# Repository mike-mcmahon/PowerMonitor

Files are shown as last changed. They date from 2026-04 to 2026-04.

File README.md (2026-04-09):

# PowerMonitor

## Table of Contents
- [Introduction](#introduction)
- [Documentation](#documentation)
- [Source Code](#source-code)

- [Information - Particle.io](#information---particleio)
- [Prerequisites To Use This Repository (Software)](#prerequisites-to-use-this-repository-software)
- [Getting Started](#getting-started)

- [License](#license)
- [Support and Feedback](#support-and-feedback)

## Introduction

This project was started to create a device that monitors AC voltage and to send push notifications to a users smartphone upon loss and restoration of power.

This device comes in handy if you ever are concerned about the loss of power in your home or at your cottage.  The user will receive push notifications via cellular (LTE CAT M1) when power is lost
and retored.  Battery backup lasts at least one day *(usually more)*.  No reliance on wifi or ethernet based network connectivity; though you should ensure you have cellular reception in the 
area you plan to deploy this.  *No subscription or data plan is required when using this device.*

For details of what this product can *currently* do for you, please read the user manual included in the documentation section of this repository.
The project was intended to be a product/device for sale; however, I have decided to open source it.  Users have the option to use these project files to make their own device, or you can optionally contact me to manufacture and program part, or all, of this project for a *fee*.  

## Documentation:

Included in this repository are the Fusion360 files for 3D models and the electronics required to make this device along with printouts of the schematics.
To use this device you will be required to:
-	Have a Particle.io account and device
-	Pushover.net account

The included user manual provides information that details the features and functionality of the device.  Additional setup guides provide instruction on proper battery installation, and on how to setup your Pushover account.
To set up your account on Particle.io see the documentation below and online at [Particle.io](https://www.particle.io/).  In the future I may provide a setup guide for creating/implementing the required custom webhook for Pushover.
*Note again that this was a device I had intended to sell, so keep this in mind while reading the documentation.*

## Source Code:

You will need VS Code installed on your system along with the Particle Workbench extension.
  
Please note that I have built this application on DeviceOS 6.0.0.

See [Getting Started](#getting-started) for further information.

## Information - Particle.io

The firmware in this project was created using [Particle Developer Tools](https://www.particle.io/developer-tools/).

## Prerequisites To Use This Repository (Software)

To use this software/firmware you'll need:

- A BRN404X [Particle Device](https://www.particle.io/devices/).
- Windows/Mac/Linux for building the software and flashing it to a device.
- [Particle Development Tools](https://docs.particle.io/getting-started/developer-tools/developer-tools/) installed and set up on your computer.  VC Code with Particle Workbench installed is recommended.
- [Pushover.net](https://pushover.net/) account set up and User key along with API token created.  See setup guide included in the documentation section of this repository.

## Getting Started

1. While not essential, it is recommended to run the [device setup process](https://setup.particle.io/) on your Particle device first. This ensures your device's firmware is up-to-date and you have a solid baseline to start from.

2. If you haven't already, open this project in Visual Studio Code (File -> Open Folder). 

3. There are two spots in the source code that you are required to update with your own information.
  - .vscode/settings.json
    - Update `"particle.targetDevice”: “xxxxxxx”` with `xxxxxxxx` being the correct device name for your Particle Device as configured on Particle.io.
  - datatransmit.cpp
    - Update `Particle.publish("yyyyyyyy", pushoverPacket, PRIVATE);` in the file datatransmit.cpp where `yyyyyyyy` is the event name you created for the custom webhook.

4. Then [compile and flash](https://docs.particle.io/getting-started/developer-tools/workbench/#cloud-build-and-flash) your device. Ensure your device's USB port is connected to your computer.

5. Refer to the user manual included in this repository on the functionality the PowerMonitor provides and verify the device is working.

## License:

Copyright (C) 2025 Mike McMahon.  Creative Commons CC BY-NC-SA 4.0 License applies to all files in this repository.  See LICENSE.md for details.

## Support and Feedback

Contact me at [mike@3rdgear.ca] or [mike@cypressembeddedsystems.ca]

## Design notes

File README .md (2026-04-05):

# PowerMonitor

Introduction:
This project was started to create a device that monitors AC voltage and to send push notifications to a users smartphone upon loss of power.
For details of what this product can (currently) do for you, please read the user manual included in the documentation section of this repository.
The project was intended to be a device for sale; however, I have decided to open source it.  Users have the option to use these project files to make their own device, or you can optionally contact me to manufacture and program parts, or all of this project for a fee.  

Documentation:
Included in this repository are the Fusion360 files for 3D models and the electronics required to make this device along with printouts of the schematics and mechanical general assembly drawings.
To use this device you will be required to:
-	Have a Particle.io account and device
-	Pushover.net account
The included user manual provides information that details the features and functionality of the device.  Additional setup guides provide instruction on proper battery installation, and on how to setup your Pushover account.
To set up your account on Particle.io see the documentation below.  In the future I may provide a setup guide for creating/implementing the required custom webhook for Pushover.
Note again that this was a device I had intended to sell, so keep this in mind while reading the documentation.

Source Code:
You will need VS Code installed on your system.
Please note that there are two spots in the source code that you are required to update with your own information.
1.	.vscode/settings.json
Update “particle.targetDevice”: “xxxxxxx” with the correct device name for your Particle Device as configured on Particle.io.
2.	Update Particle.publish("yyyyyyyy", pushoverPacket, PRIVATE); in the file datatransmit.cpp where “yyyyyyyy” is the event name you created for the custom webhook.
Please note that I have built this application on DeviceOS 6.0.0.

License:
Copyright (C) 2025 Mike McMahon.  Creative Commons CC BY-NC-SA 4.0 License applies to all files in this repository.  See LICENSE.md for details.

~~~~~~~~~~~~~~~~~~~~~~~~~~~~~~~~~~~~~~~~~~~~~~~~~~~~~~~~~~~~~~~~~~~~~~~~~~~~~~~~~~~~~~~~~~~~~~~~~~~~~~~~~~~~~~~~~~~~~~~~~~~~~~~~~~~~~~~~~~~~~~~~~
~~~~~~~~~~~~~~~~~~~~~~~~~~~~~~~~~~~~~~~~~~~~~~~~~~~~~~~~~~~~~~~~~~~~~~~~~~~~~~~~~~~~~~~~~~~~~~~~~~~~~~~~~~~~~~~~~~~~~~~~~~~~~~~~~~~~~~~~~~~~~~~~~
Autogenerated file information from Particle Workbench

# PowerMonitor

This firmware project was created using [Particle Developer Tools](https://www.particle.io/developer-tools/) and is compatible with all [Particle Devices](https://www.particle.io/devices/).

Feel free to replace this README.md file with your own content, or keep it for reference.

## Table of Contents
- [Introduction](#introduction)
- [Prerequisites To Use This Template](#prerequisites-to-use-this-repository)
- [Getting Started](#getting-started)
- [Particle Firmware At A Glance](#particle-firmware-at-a-glance)
  - [Logging](#logging)
  - [Setup and Loop](#setup-and-loop)
  - [Delays and Timing](#delays-and-timing)
  - [Testing and Debugging](#testing-and-debugging)
  - [GitHub Actions (CI/CD)](#github-actions-cicd)
  - [OTA](#ota)
- [Support and Feedback](#support-and-feedback)
- [Version](#version)

## Introduction

For an in-depth understanding of this project template, please refer to our [documentation](https://docs.particle.io/firmware/best-practices/firmware-template/).

## Prerequisites To Use This Repository

To use this software/firmware on a device, you'll need:

- A [Particle Device](https://www.particle.io/devices/).
- Windows/Mac/Linux for building the software and flashing it to a device.
- [Particle Development Tools](https://docs.particle.io/getting-started/developer-tools/developer-tools/) installed and set up on your computer.
- Optionally, a nice cup of tea (and perhaps a biscuit).

## Getting Started

1. While not essential, we recommend running the [device setup process](https://setup.particle.io/) on your Particle device first. This ensures your device's firmware is up-to-date and you have a solid baseline to start from.

2. If you haven't already, open this project in Visual Studio Code (File -> Open Folder). Then [compile and flash](https://docs.particle.io/getting-started/developer-tools/workbench/#cloud-build-and-flash) your device. Ensure your device's USB port is connected to your computer.

3. Verify the device's operation by monitoring its logging output:
    - In Visual Studio Code with the Particle Plugin, open the [command palette](https://docs.particle.io/getting-started/developer-tools/workbench/#particle-commands) and choose "Particle: Serial Monitor".
    - Or, using the Particle CLI, execute:
    ```
    particle serial monitor --follow
    ```

4. Uncomment the code at the bottom of the cpp file in your src directory to publish to the Particle Cloud! Login to console.particle.io to view your devices events in real time.

5. Customize this project! For firmware details, see [Particle firmware](https://docs.particle.io/reference/device-os/api/introduction/getting-started/). For information on the project's directory structure, visit [this link](https://docs.particle.io/firmware/best-practices/firmware-template/#project-overview).

## Particle Firmware At A Glance

### Logging

The firmware includes a [logging library](https://docs.particle.io/reference/device-os/api/logging/logger-class/). You can display messages at different levels and filter them:

```
Log.trace("This is trace message");
Log.info("This is info message");
Log.warn("This is warn message");
Log.error("This is error message");
```

### Setup and Loop

Particle projects originate from the Wiring/Processing framework, which is based on C++. Typically, one-time setup functions are placed in `setup()`, and the main application runs from the `loop()` function.

For advanced scenarios, explore our [threading support](https://docs.particle.io/firmware/software-design/threading-explainer/).

### Delays and Timing

By default, the setup() and loop() functions are blocking whilst they run, meaning that if you put in a delay, your entire application will wait for that delay to finish before anything else can run. 

For techniques that allow you to run multiple tasks in parallel without creating threads, checkout the code example [here](https://docs.particle.io/firmware/best-practices/firmware-template/).

(Note: Although using `delay()` isn't recommended for best practices, it's acceptable for testing.)

### Testing and Debugging

For firmware testing and debugging guidance, check [this documentation](https://docs.particle.io/troubleshooting/guides/build-tools-troubleshooting/debugging-firmware-builds/).

### GitHub Actions (CI/CD)

This project provides a YAML file for GitHub, automating firmware compilation whenever changes are pushed. More details on [Particle GitHub Actions](https://docs.particle.io/firmware/best-practices/github-actions/) are available.

### OTA

To learn how to utilize Particle's OTA service for device updates, consult [this documentation](https://docs.particle.io/getting-started/cloud/ota-updates/).

Test OTA with the 'Particle: Cloud Flash' command in Visual Studio Code or the CLI command 'particle flash'!

This firmware supports binary assets in OTA packages, allowing the inclusion of audio, images, configurations, and external microcontroller firmware. More details are [here](https://docs.particle.io/reference/device-os/api/asset-ota/asset-ota/).

## Support and Feedback

For support or feedback on this template or any Particle products, please join our [community](https://community.particle.io)!

## Version

Template version 1.0.2

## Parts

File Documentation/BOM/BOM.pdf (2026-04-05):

Miscellaneous BOM Items

Component | Part Number | Description | Qty | UoM | Vendor
Inserts | n/a | 5mm brass threaded inserts | 4 | each | Amazon
Screws | 99461A942 | 18-8 SS thread forming screw, M3x10mm | 9 | each | McMaster-Car
Screws | 91294A128 | M3x8mm flat head screw | 4 | each | McMaster-Car
Power Supply | DC23U | SoulBay DC23U micro USB 5Vdc ps | 1 | each | Amazon
Battery | MAK010-P | Mbot Slim Lipo Battery, 3.7V 1800mAh | 1 | each | RobotShop

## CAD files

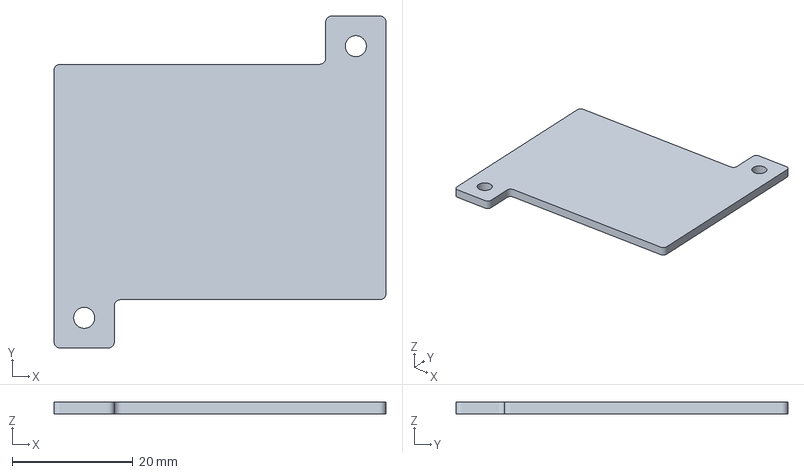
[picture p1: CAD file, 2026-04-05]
Documentation/Fusion360 CAD Models/PrusaSlicer Project Files/Battery Cover/Battery Cover v7 - Spectrum ASA-X GF10.3mf
55.0 x 55.0 x 2.00 mm

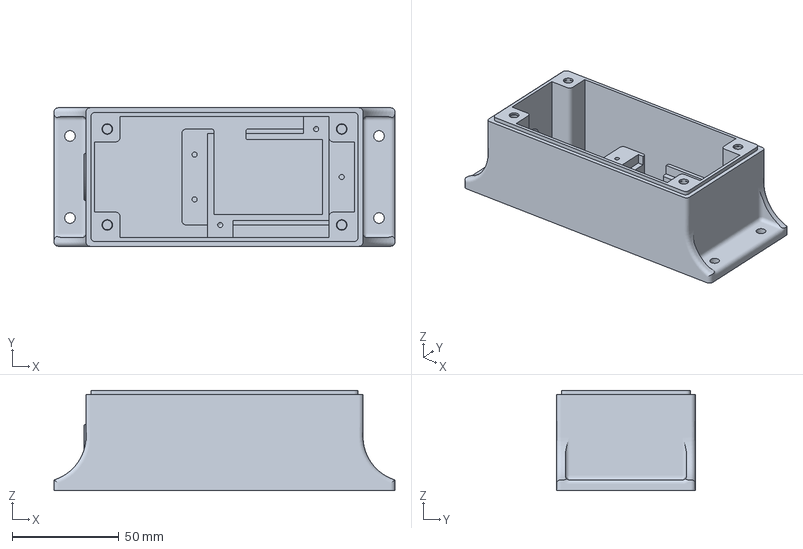
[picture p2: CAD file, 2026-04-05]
Documentation/Fusion360 CAD Models/PrusaSlicer Project Files/Enclosure Bottom/Power Monitor Enclosure Bottom v34 - Spectrum ASA-X GF10.3mf
160.0 x 65.0 x 47.0 mm

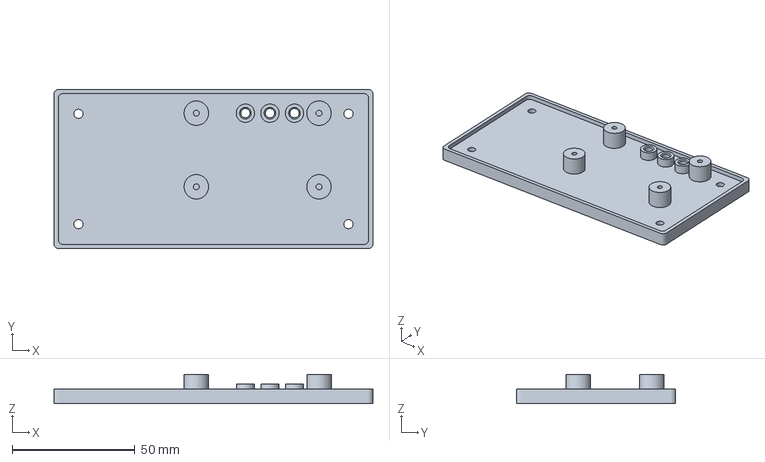
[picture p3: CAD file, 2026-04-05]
Documentation/Fusion360 CAD Models/PrusaSlicer Project Files/Enclosure Lid/Enclosure Lid v23 - Spectrum ASA-X GF10.3mf
130.0 x 65.0 x 12.0 mm

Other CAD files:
Documentation/Fusion360 CAD Models/Fusion360/Battery Cover/Battery Cover.f3d
Documentation/Fusion360 CAD Models/Fusion360/Enclosure Bottom/Power Monitor Enclosure Bottom.f3d
Documentation/Fusion360 CAD Models/Fusion360/Enclosure Lid/Enclosure Lid.f3d
Documentation/Fusion360 Electrical/Carrier Board/BRN404X Carrier Board.f3z
Documentation/Fusion360 Electrical/LED Board/Power Monitor Electronics Design.f3z

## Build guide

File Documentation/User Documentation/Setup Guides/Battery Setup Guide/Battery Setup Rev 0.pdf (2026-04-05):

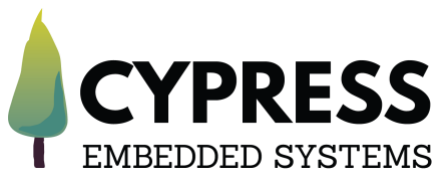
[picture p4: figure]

Cypress Embedded Systems | Setup Guide rev. 0

©2025 Michael McMahon, Cypress Embedded Systems. All rights reserved. This work is licensed under a Creative Commons Attribution-NonCommercial-ShareAlike 4.0 International License. You should have received a copy of the license along with this work. If not, see http://creativecommons.org/licenses/by-nc-sa/4.0/.

# PowerMonitor AC Line Voltage Monitoring Device Setup Guide

IMPORTANT! The following instructions are to be followed before using the PowerMonitor for the first time.

INFORMATION

1) Read the user manual for the PowerMonitor and become familiar with its external and internal features.
2) Plug in the battery before first use.
a. Unscrew the four (4) M3 flat head screws using the supplied Allen key, and remove the cover.
b. READ THE SECTION ON INTERNAL FEATURES IN THE USER MANUAL. The JST battery connectors are polarized. There is no reverse polarity protection on this unit. Damage from connecting the battery incorrectly is not covered by any warranty.
c. Connect the battery to the main control board as shown in the User Manual.
d. Put the cover back onto the PowerMonitor and secure it with the same four (4) screws that were removed in step a.
3) You may now use the PowerMonitor with the supplied microUSB power supply.

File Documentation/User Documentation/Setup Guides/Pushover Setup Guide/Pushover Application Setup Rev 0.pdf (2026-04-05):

## PowerMonitor AC Line Voltage Monitoring Device – Pushover Application Setup

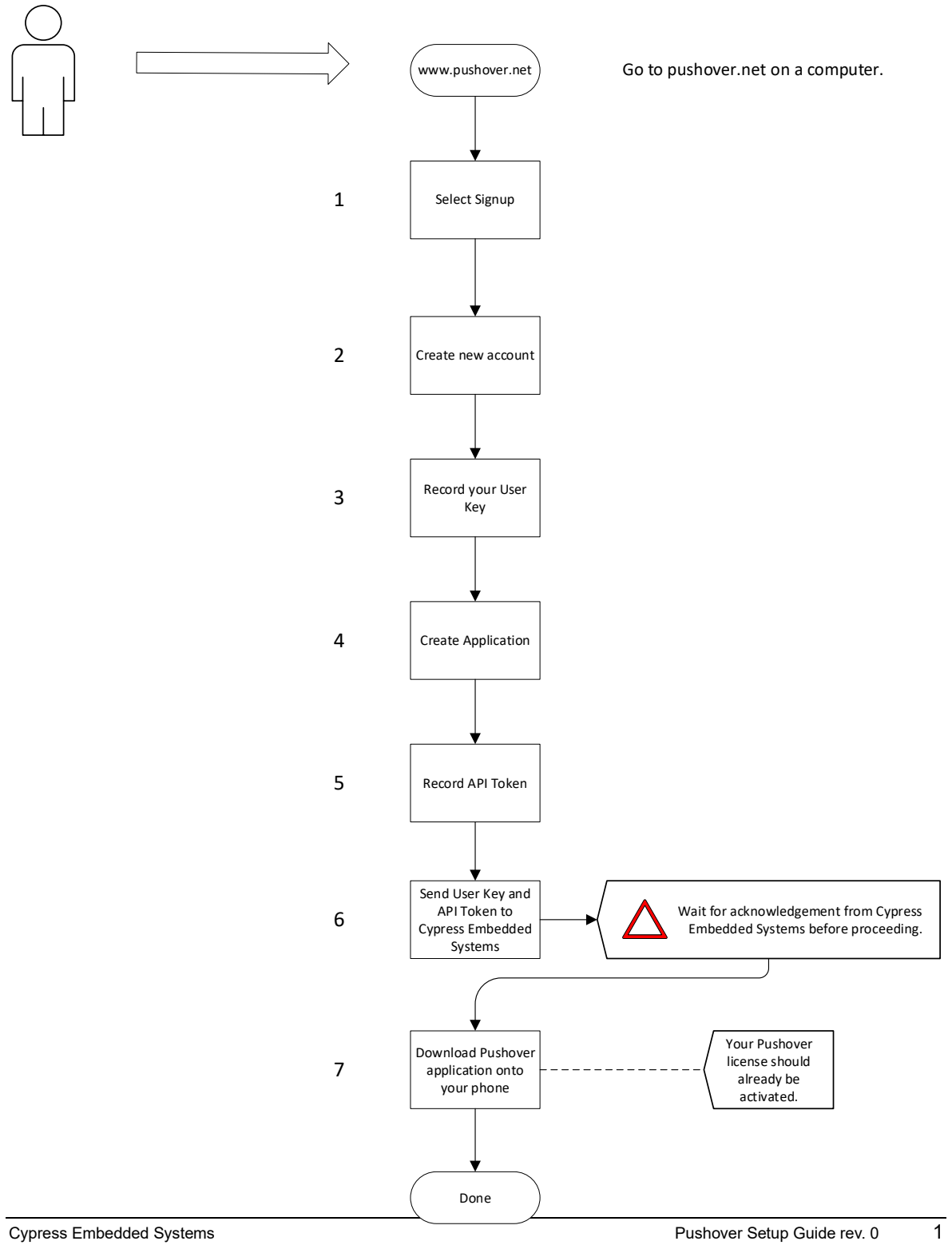
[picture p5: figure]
Cypress Embedded Systems; Pushover Setup Guide rev. 0; Select Signup; Create new account; Record your User Key; Create Application; Record API Token; Send User Key and API Token to Cypress Embedded Systems; Download Pushover application onto your phone; Done; Your Pushover license should already be activated.; Wait for acknowledgement from Cypress Embedded Systems before proceeding.

©2025 Michael McMahon, Cypress Embedded Systems. All rights reserved. This work is licensed under a Creative Commons Attribution-NonCommercial-ShareAlike 4.0 International License. You should have received a copy of the license along with this work. If not, see http://creativecommons.org/licenses/by-ncsa/4.0/.

www.pushover.net | Go to pushover.net on a computer.

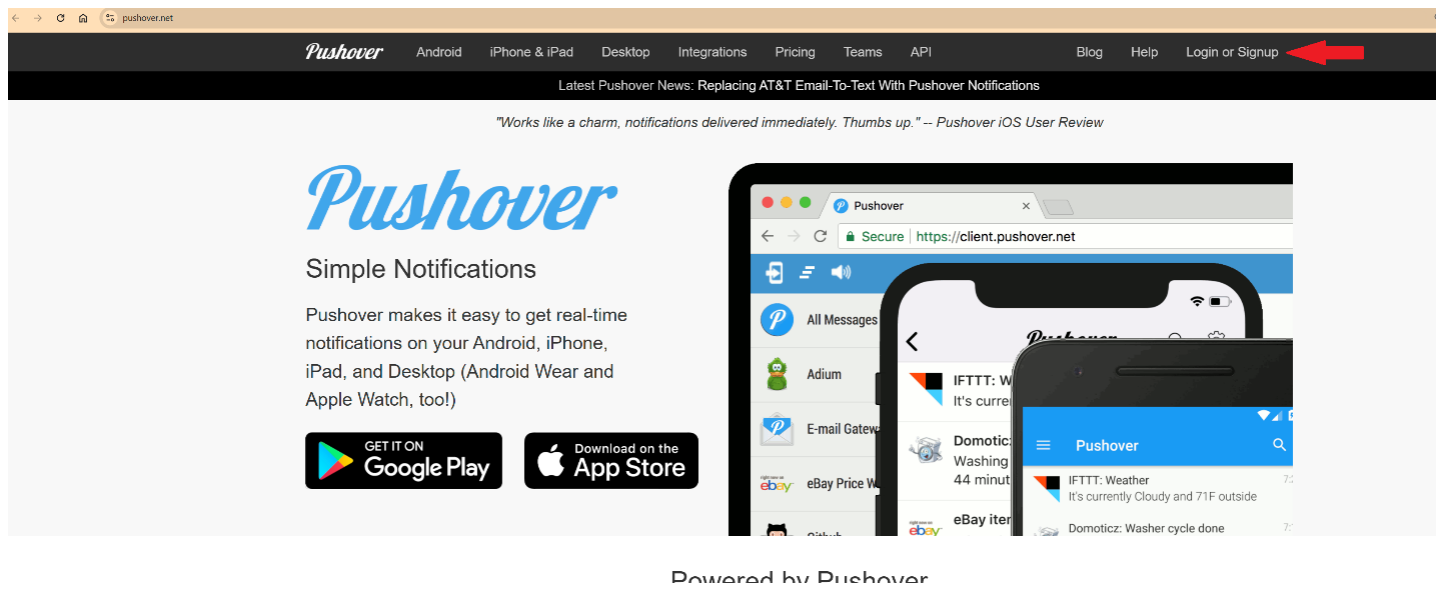
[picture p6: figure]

Cypress Embedded Systems | Pushover Setup Guide rev. 0 | 2

©2025 Michael McMahon, Cypress Embedded Systems. All rights reserved. This work is licensed under a Creative Commons Attribution-NonCommercial-

### 1. Select Signup

a. From a computer, open the website pushover.net.
b. In the top right corner of Figure 1 - Pushover landing page, click on “Login or Signup”.

## Figure 1 - Pushover landing page

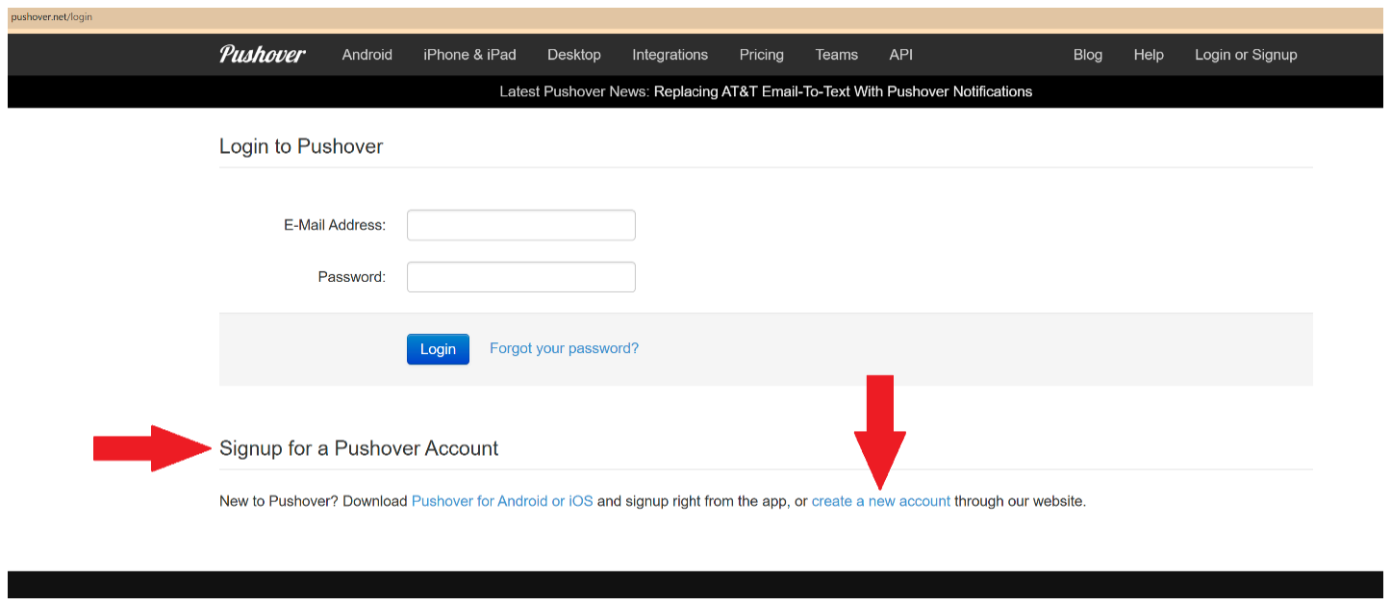
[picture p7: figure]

Cypress Embedded Systems | Pushover Setup Guide rev. 0 | 3

©2025 Michael McMahon, Cypress Embedded Systems. All rights reserved. This work is licensed under a Creative Commons Attribution-NonCommercial-

### 2. Create new account a. From the new web page that opened, Figure 2 - Create a new account, select the link to

"create a new account".

## Figure 2 - Create a new account

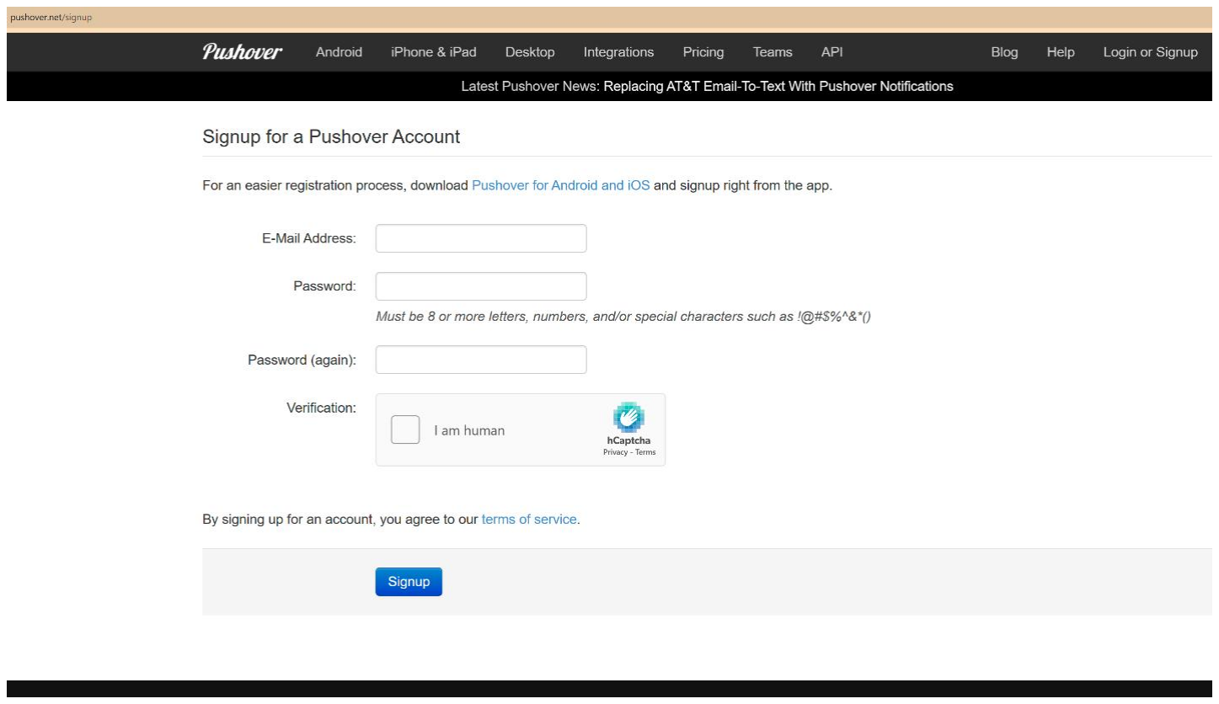
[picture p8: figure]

Cypress Embedded Systems | Pushover Setup Guide rev. 0 | 4

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

### b. On the page that opens, Figure 3 – Signup for a Pushover Account, enter your email address and password. Make sure to record and remember the email address and

password you used.

INFORMATION

Yor are responsible for saving and maintaining this information.

# This information will be needed later when you set up the

Pushover application on your smartphone.

c. Click on the box "I am human".
d. Click on the button "Signup".

## Figure 3 – Signup for a Pushover Account

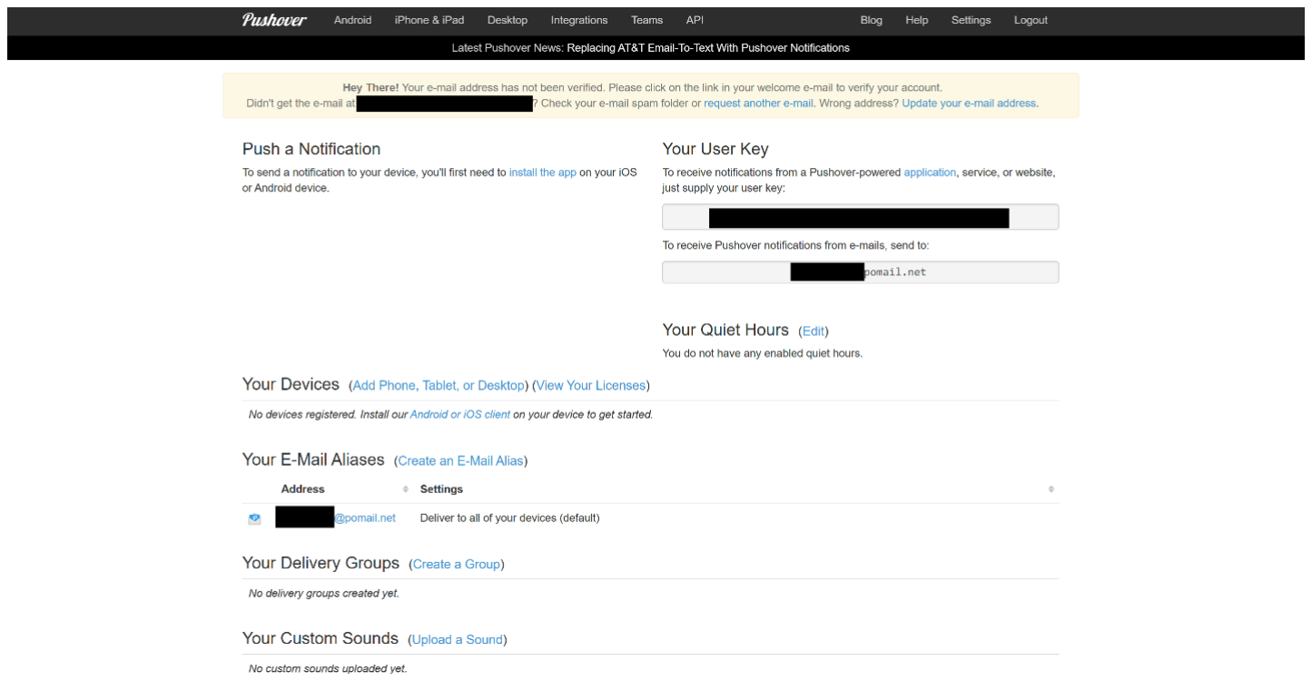
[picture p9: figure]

Cypress Embedded Systems | Pushover Setup Guide rev. 0 | 5

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

### e. Once your account is created, you will be redirected to the Pushover home page, Figure

4 - Account home page, for your account.

INFORMATION

# You will also receive an email from Pushover to verify your

account. Follow the directions in this email.

## Figure 4 - Account home page

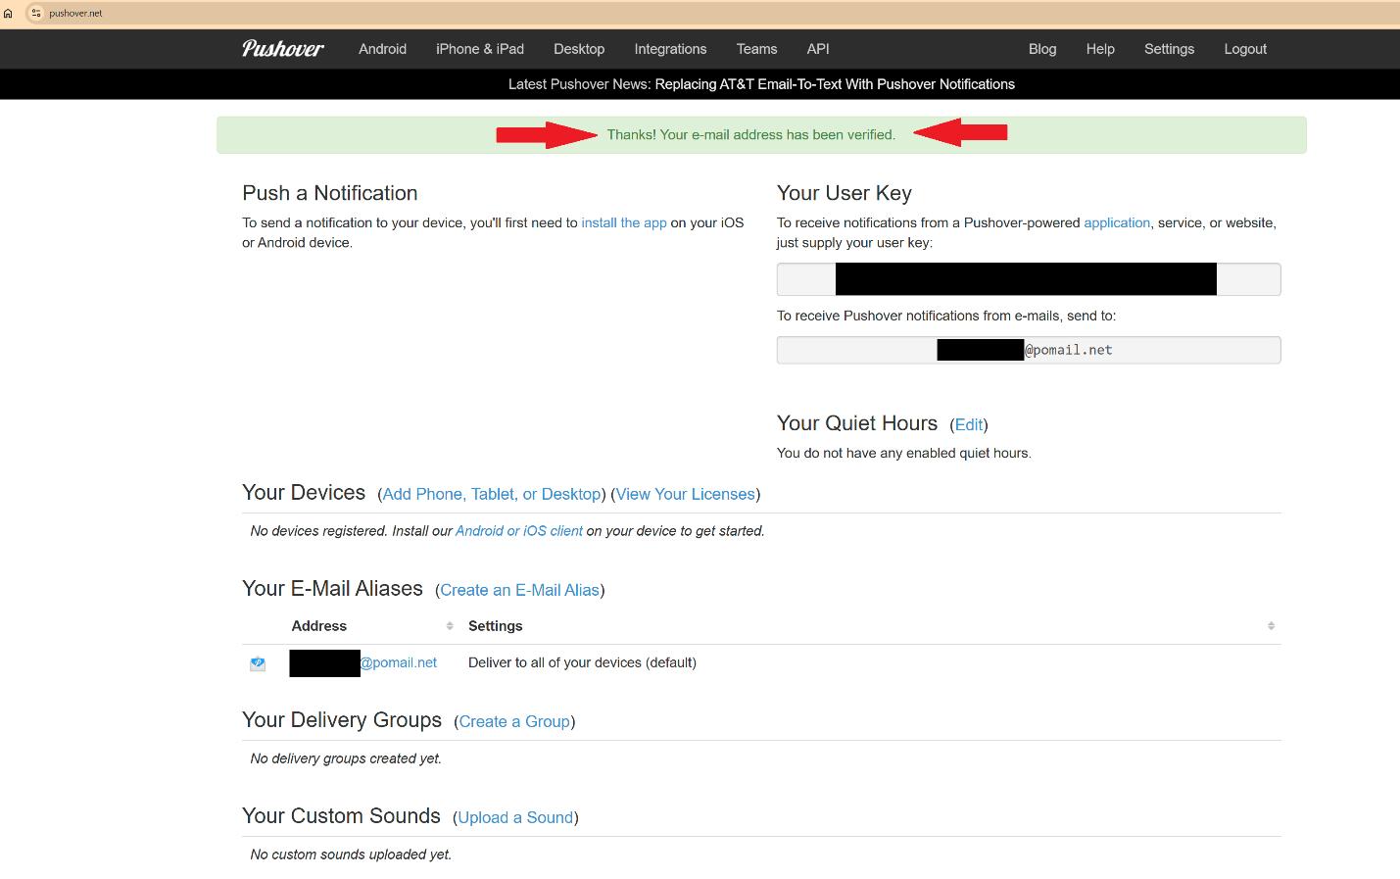
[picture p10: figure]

Cypress Embedded Systems | Pushover Setup Guide rev. 0 | 6

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

### f. Once your account is verified, there will be a green banner shown at the top of your

account home page as shown in Figure 5 - Verified account home page.

## Figure 5 - Verified account home page

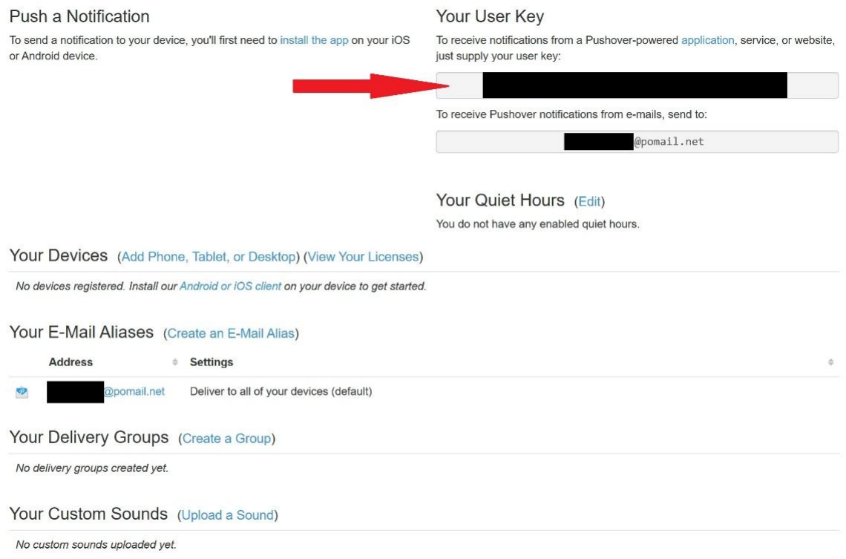
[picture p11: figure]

Cypress Embedded Systems | Pushover Setup Guide rev. 0 | 7

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

### 3. Record your User Key a. At the top right side of the account home page is "Your User Key', see Figure 6 - User Key. This is an alphanumeric string. Please take a screenshot of this and save it to your

computer.

INFORMATION

# You will need to send your user key to Cypress Embedded Systems. This is one of two pieces of information that are needed

to get your PowerMonitor to work.

## Figure 6 - User Key

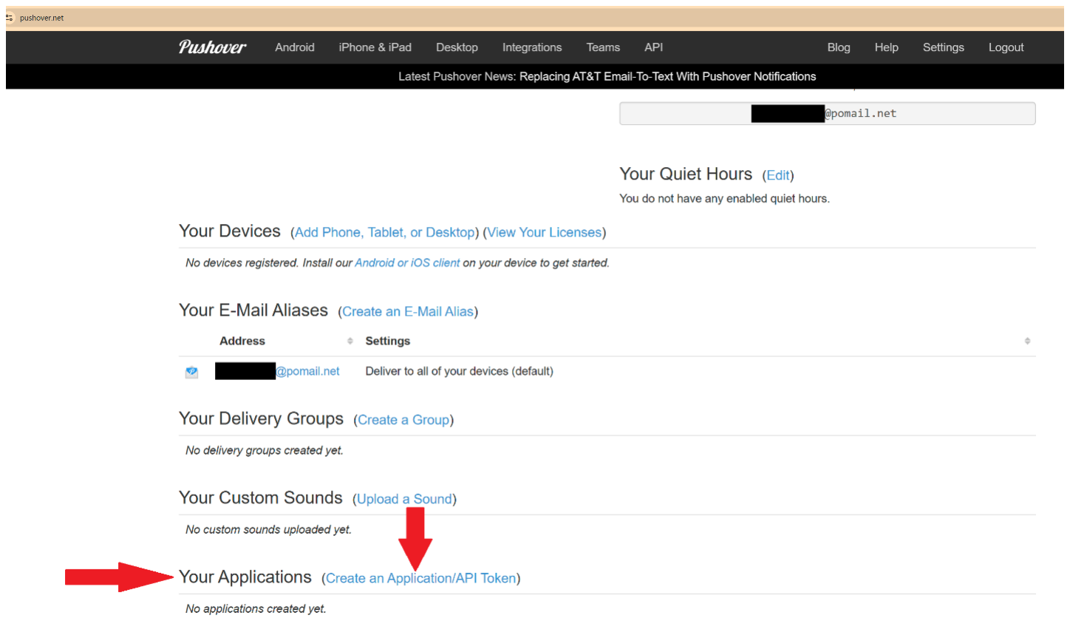
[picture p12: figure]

Cypress Embedded Systems | Pushover Setup Guide rev. 0 | 8

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

### 4. Create Application a. At the bottom of your account home page is a section called "Your Applications", see

Figure 7 - Your Applications. Click on the link called "Create an Application/API Token".

## Figure 7 - Your Applications

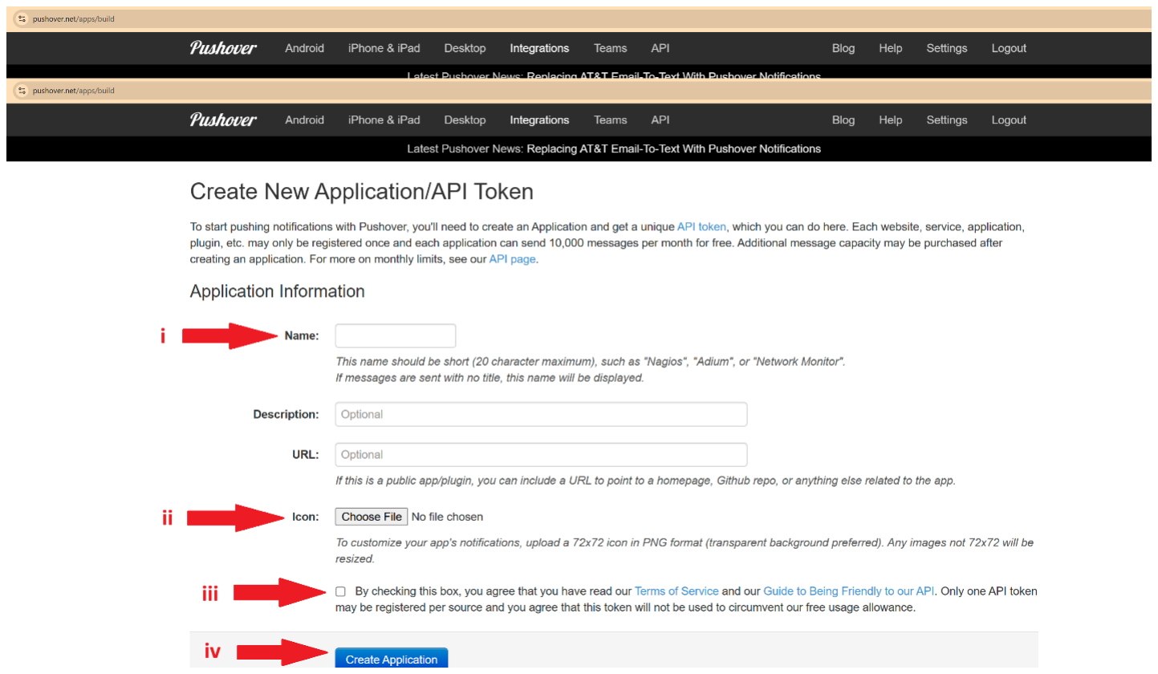
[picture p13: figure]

Cypress Embedded Systems | Pushover Setup Guide rev. 0 | 9

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

### b. On the web page "Create New Application/API Token", see Figure 8 - Create New

Application/API Token, perform the following steps.
i. Enter the name "PowerMonitor" in the Name field.

### ii. (OPTIONAL) By default, push notifications received by this application use the Pushover icon. If you like you can use an icon we (can) provide, or one of your

choice or creation.
iii. Check off the box accepting the terms of service.
iv. Click on the button "Create Application".

## Figure 8 - Create New Application/API Token

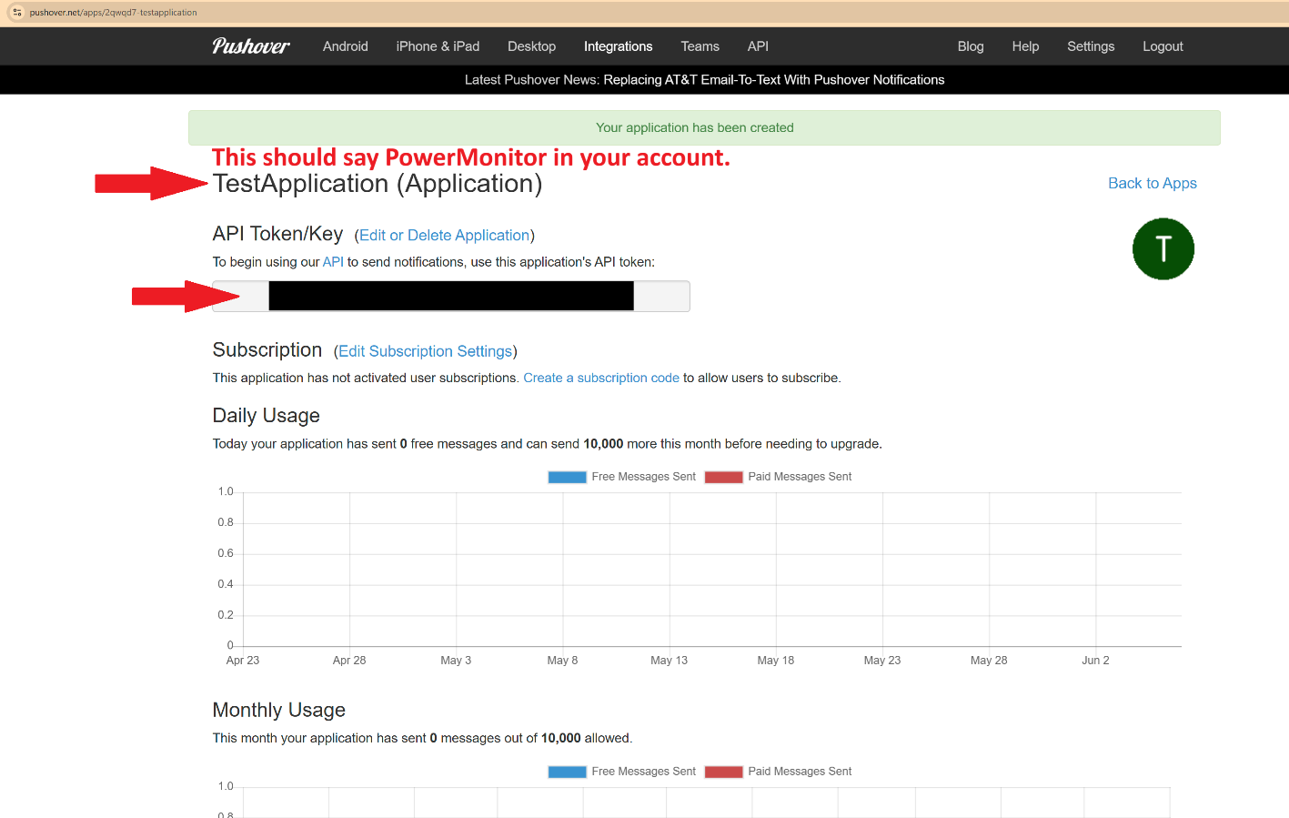
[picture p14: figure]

Cypress Embedded Systems | Pushover Setup Guide rev. 0 | 10

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

### 5. Record API Token

a. After creating the application, you will be taken to the applications web page, see Figure 9 - Application Created. At the top of this page will be application API Token/Key that was created. Take a screenshot of this API Token and save it to your computer.

INFORMATION

# You will need to send your user API Token to Cypress Embedded Systems. This is the second piece of information that is needed to

get your PowerMonitor to work.

## Figure 9 - Application Created

Cypress Embedded Systems | Pushover Setup Guide rev. 0 | 11

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

### 6. Send User Key and API Token to Cypress Embedded Systems a. Email your User Key and API Token to mike@cypressembeddedsystems.ca. This

information is critical for getting your PowerMonitor to work.

### b. After completing the last step you can return to your account home page and log out of

the desktop application.

INFORMATION

# After completing this step you can return to your account home

page and log out of the desktop application.

# Send your User Key, the application API Token, and what device

platforms you will be using to Cypress Embedded Systems.

# Pushover is an application that requires a license to operate after a 30 day evaluation period. The PowerMonitor device includes a

license for up to two device platforms, Android or Apple iOS.

# Multiple devices of the same platform are covered under the same

license.

# Wait for a response from Cypress Embedded Systems before

proceeding to the next step.

7. Download Pushover application onto your phone a. Once you have received confirmation back from Cypress Embedded Systems that your information has been received and processed, download the Pushover application onto each smartphone you plan to use with your PowerMonitor device. Use the same login credentials on each device. Each device you login with will be recorded on your

Pushover account, and the license should automatically be activated.

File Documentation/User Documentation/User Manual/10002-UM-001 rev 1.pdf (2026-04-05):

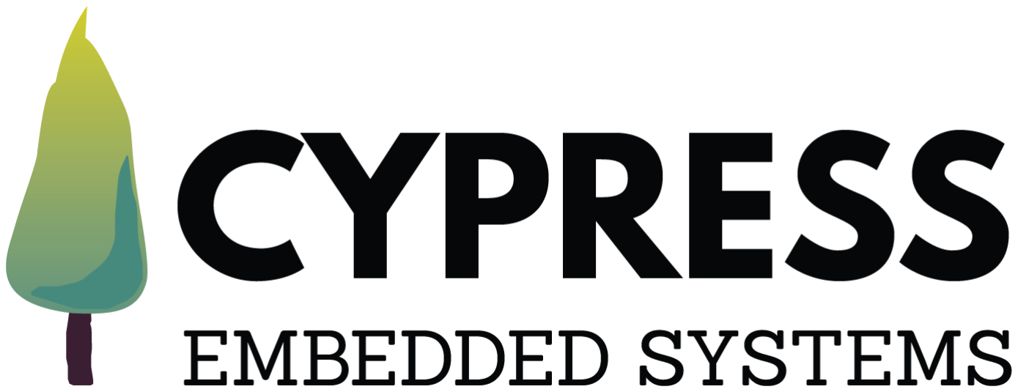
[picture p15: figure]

# PowerMonitor

# AC Line Voltage Monitoring Device

# User Manual

10002-UM-001

# Revision 1

PowerMonitor - AC Line Power Monitoring Module
User Manual | May 2025
Cypress Embedded Systems | 10002-UM-001 rev. 1

©2025 Michael McMahon, Cypress Embedded Systems. All rights reserved. This work is licensed under a Creative Commons Attribution-NonCommercial-ShareAlike 4.0 International License. You should have received a copy of the license along with this work. If not, see http://creativecommons.org/licenses/by-nc-sa/4.0/.

2

## Table of Contents

Cypress Embedded Systems | 10002-UM-001 rev. 1

©2025 Michael McMahon, Cypress Embedded Systems. All rights reserved. This work is licensed under a Creative Commons Attribution-NonCommercial-

3

## Revision History

Prepared by | Date | Details of Revision | Revision
M. McMahon | 04/12/2025 | AC line power monitor prototype – User Manual. | 0
M. McMahon | 05/24/2025 | Expanded instructions and warnings on handling of lithium polymer batteries. Update LED indicator functionality. | 1

## Approvals

Prepared by:

Mike McMahon – Cypress Embedded Systems

Cypress Embedded Systems | 10002-UM-001 rev. 1

©2025 Michael McMahon, Cypress Embedded Systems. All rights reserved. This work is licensed under a Creative Commons Attribution-NonCommercial-

4

## Introduction

### Welcome

Thank you for purchasing the PowerMonitor - AC Line Voltage Monitoring device by Cypress Embedded Systems.

This device is designed to monitor for the loss and restoration of AC line voltage and sending push notifications to the user via a cellular LTE network connection.

The device comes equipped with status indicators which provide status information at a quick glance.

## Warranty Coverage

Cypress Embedded Systems ("Manufacturer") warrants that the PowerMonitor ("Product") will be free from defects in materials and workmanship under normal use for a period of twelve (12) months from the date of original purchase (“Warranty Period”).

Exclusions:
This warranty does not cover:
i. The supplied lithium battery, which is provided "as-is" and without warranty.
ii. | Damage resulting from misuse, abuse, neglect, accident, unauthorized modification, improper
| installation, or use outside the Product’s intended purpose.
iii. | Normal wear and tear or cosmetic damage.
iv. | Damage caused by external factors such as power surges, water exposure, or extreme
| environmental conditions.

Remedy:
If a defect arises and a valid claim is received within the Warranty Period, Cypress Embedded Systems will, at its sole discretion, repair or replace the defective PowerMonitor or component with a new or refurbished part. Replacement parts or products assume the remaining warranty of the original Product or ninety (90) days, whichever is longer.

Limitation of Liability:
To the maximum extent permitted by applicable law, Cypress Embedded Systems’ total liability under this warranty shall be limited to the original purchase price of the PowerMonitor. Under no circumstances shall Cypress Embedded Systems be liable for any indirect, incidental, consequential, or special damages, including but not limited to loss of profits, data, or use, arising from or related to the use or inability to use the PowerMonitor.

How to Obtain Warranty Service:
To make a warranty claim, contact Cypress Embedded Systems at mike@cypressembeddedsystems.ca or mike@3rdgear.ca with proof of purchase, a description of the issue, and your contact details. The PowerMonitor may need to be returned to the Manufacturer for evaluation. Please include the text “PowerMonitor Warranty Claim” in the subject line of your email when making a warranty claim.

Cypress Embedded Systems | 10002-UM-001 rev. 1

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

5

Governing Law:
This warranty shall be governed by and construed in accordance with the laws of the Province of Ontario, Canada.

## Battery Liability Disclaimer

By using the PowerMonitor, which contains a Lithium Polymer (LiPo) battery, the user acknowledges and agrees to the following:

i. Cypress Embedded Systems ("Manufacturer") assumes no liability for any damage, injury, or loss arising from the use, handling, or malfunction of the Lithium Polymer battery inside the device.
ii. | The Lithium Polymer battery is supplied as-is, and the Manufacturer makes no representations
| or warranties regarding its performance, safety, or suitability for any particular use.
iii. | The user agrees to follow all manufacturer-recommended safety guidelines for the handling,
| charging, and disposal of the battery. The Manufacturer is not responsible for any consequences
| resulting from improper handling or failure to follow safety instructions.
iv. | The Manufacturer is not liable for any direct, indirect, incidental, or consequential damages,
| including, but not limited to, injury, fire, or property damage, caused by the failure or misuse of the
| Lithium Polymer battery.

By using the PowerMonitor, the user assumes full responsibility for the care and safe use of the Lithium Polymer battery and agrees to hold Cypress Embedded Systems harmless from any liability related to the battery's performance or risks.

## Cellular Connectivity and Return Policy

Please note that this device is not returnable due to its inability to connect to a LTE cellular network. It is the customer’s sole responsibility to ensure that there is adequate cellular coverage in the area the PowerMonitor is intended to be installed before purchasing the device. Lack of connectivity resulting from insufficient network coverage, carrier compatibility, or other location-based limitations does not qualify as a valid reason for return or refund.

Please refer to the section LTE in this manual for additional information.

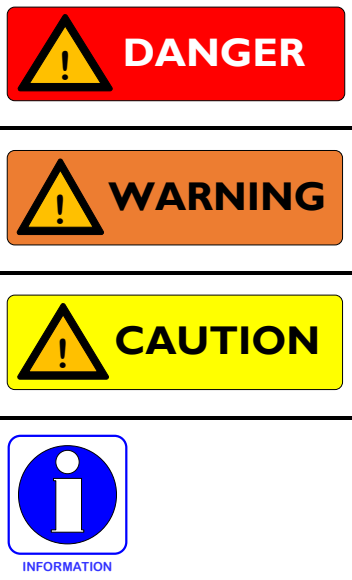
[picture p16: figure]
DANGER !; ! WARNING; ! CAUTION; INFORMATION

Cypress Embedded Systems | 10002-UM-001 rev. 1

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

6

## General Considerations and Safety Information

### Document Notation

This document uses four levels of notation to highlight important information and warnings.

Warns that failure to comply could result in serious injury or damage to property.

Warns that failure to comply could result in minor or moderate injury or damage to property.

Warns that failure to comply may result in property damage.

Notes provide additional information, emphasize a point, or provide a tip.

### Document Conventions

All dimensions referenced in this document are metric unless otherwise stated.

### Operating Environment

The PowerMonitor device is intended for indoor use only. Use and store in a dry area at ambient room temperature (20-25° C), and out of direct sunlight.

### Assumptions

It is assumed that users have the Pushover application installed on their smartphone and account set up. The Pushover application can be downloaded from the Apple App store (for iPhone) or Google Play (for Android). Installation and configuration of this application are outside the scope of this document. Users can access their Pushover account at www.pushover.net.

### Cleaning

If the unit requires cleaning use a clothe lightly dampened with water only and wipe all exterior surfaces clean.

Cypress Embedded Systems | 10002-UM-001 rev. 1

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

7

## ! WARNING

Do not use harsh chemicals, solvents, or detergents to clean this device.

Do not submerge this device in water or expose it to rain or adverse atmospheric conditions.

Mishandling from:
- Dropping this device,
- Exposing this device to extreme temperatures or moisture,
- Using this device in a way that is not intended or specified in this manual, or
- Tampering with this device or attempting to repair it without authorization
shall void all warranties implied or otherwise stated.

Cypress Embedded Systems | 10002-UM-001 rev. 1

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

8

### Lithium Batteries

Many products we use today such as our smart phones, laptops, tablet computers, and other digital devices use lithium ion or lithium polymer batteries. While we may not think of it, these batteries come with risks with their use. Care must be taken when handling and using devices with these types of batteries installed.

Note that this product contains a lithium polymer battery.

## DANGER !

Do not drop, throw, modify, or tamper with lithium-ion batteries.

Do not use batteries that are swollen, dented, or show other signs of damage.

Store and use batteries in a dry location at room temperature, away from direct sunlight and extreme temperatures.

Dispose of batteries properly through designated recycling programs.

Do not overcharge batteries and ensure they are charged in a wellventilated area, away from soft surfaces.

INFORMATION

This device charges and provides limited monitoring of the battery state as explained further in this manual.

Do not use any other means of charging the internal lithium battery. Using an external charger can result in damage to the battery, the

Cypress Embedded Systems | 10002-UM-001 rev. 1

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

9

### Periodic Checks

The internal lithium polymer battery should be inspected every three (3) months. A visual inspection should look for:
- Swollen, dented battery.
- Any signs of physical damage.

INFORMATION

Nominal battery voltage is 3.7Vdc. A fully charged battery should be approximately 4.2Vdc.

## ! CAUTION

If the battery has been charged for a long period of time and the battery is not holding a charge, or the voltage is less than 3.2Vdc, replace the battery.

Do not continue to use lithium ion/lithium polymer batteries that show signs of damage or will not hold a charge.

If required, batteries can be purchased from Cypress Embedded Systems. Contact mike@cypressembeddedsystems.ca. A replacement battery can also be purchased directly from https://ca.robotshop.com/.

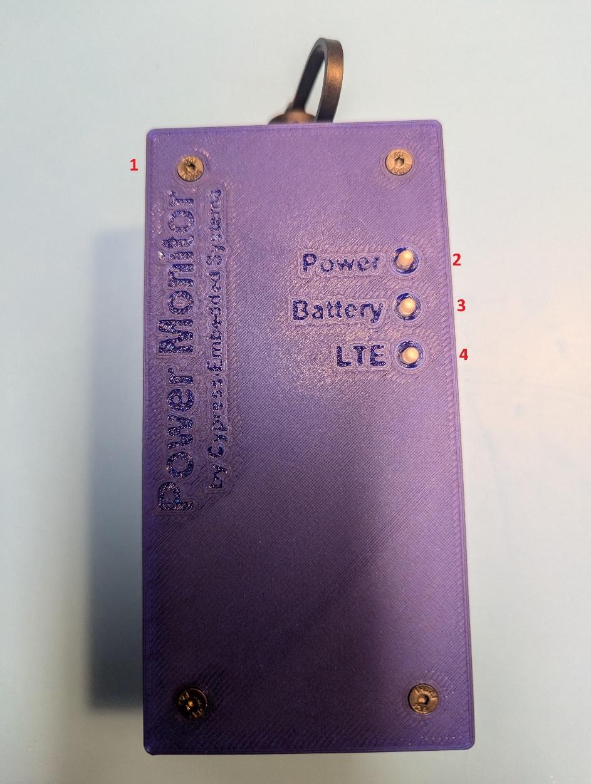
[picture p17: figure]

Cypress Embedded Systems | 10002-UM-001 rev. 1

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

10

## Device Features

### External Features

The PowerMonitor is housed in an enclosure with dimensions as shown in the section Drawings. External features of the device are shown in the figures below.

Enclosure Front

Figure 1 - Enclosure Front

1- (Qty 4) M3 x 8mm Flat Head Screws (hex socket) 2- Power Status indicator LED
3- Battery Status indicator LED
4- Cellular (LTE) Status indicator LED

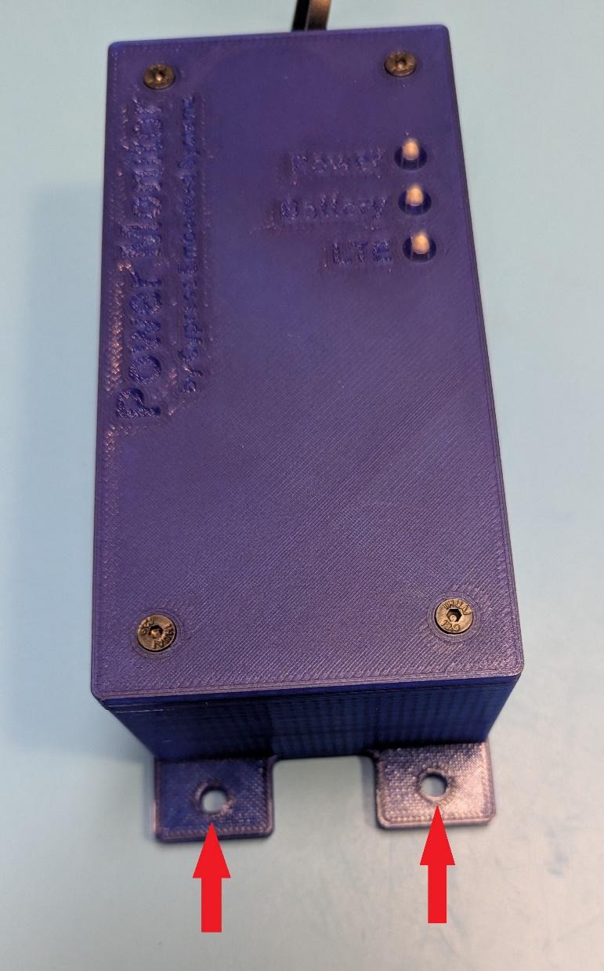
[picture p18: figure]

Cypress Embedded Systems | 10002-UM-001 rev. 1

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

11

Enclosure Mounting Tabs

Figure 2 - Mounting Tabs

The PowerMonitor includes four mounting tabs; two at the top (not shown) and two at the bottom. The holes will accept screws up to a diameter of 5mm.

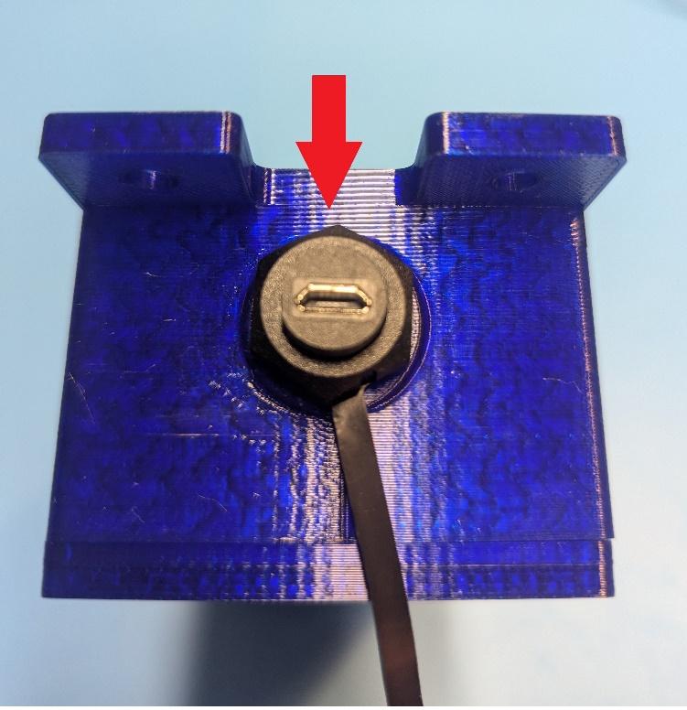
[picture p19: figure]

Cypress Embedded Systems | 10002-UM-001 rev. 1

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

12

USB Power and Communications

Figure 3 – Micro-USB Power Connector

The PowerMonitor includes a Micro-USB connector at the top (with dust cover). The connector’s primary use is to power the device with the included DC power adaptor. Additionally, the Micro-USB connector allows the device to connect to a computer for firmware updates.

INFORMATION

The included DC power adaptor is rated for 5Vdc, 3A and has a male Micro-USB connector that plugs into the PowerMonitor’s power connector. If a replacement power adaptor is needed, ensure its output is 5Vdc and at minimum 1A.

## ! CAUTION

Ensure the supplied DC power adaptor is kept in good condition and free from excessive wear or damage. Replace the power adaptor if it has been mishandled or shows signs of wear or damage.

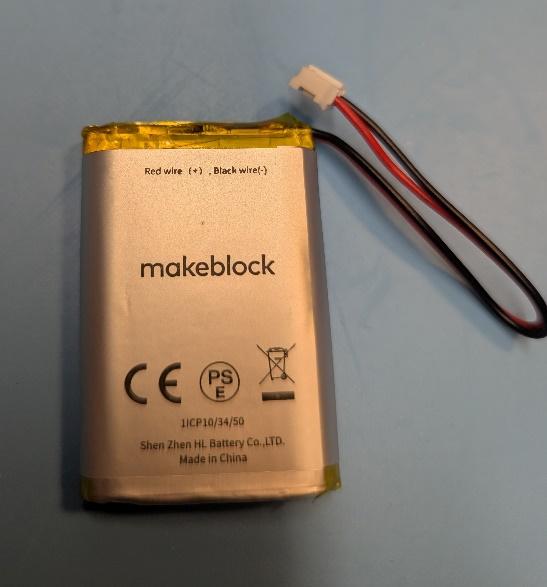
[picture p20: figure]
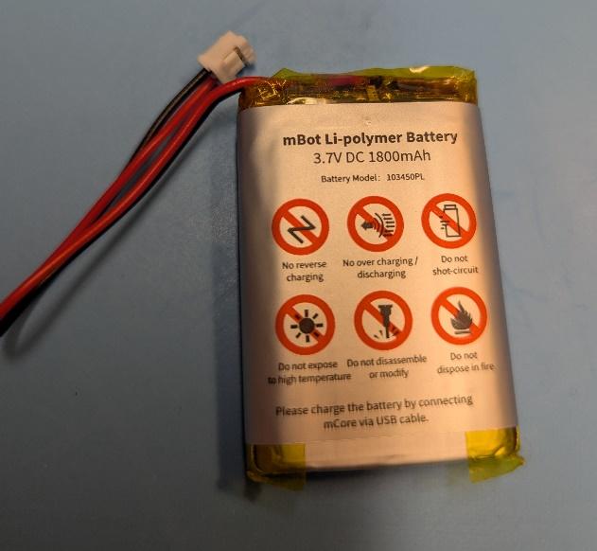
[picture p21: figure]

Cypress Embedded Systems | 10002-UM-001 rev. 1

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

13

### Internal Features

The following describes the internal features of the device.

Battery

Figure 4 - Lithium Polymer Battery

The PowerMonitor is supplied with a single cell, 3.7Vdc, 1800mAh lithium polymer battery. The battery serves as a backup power supply for the PowerMonitor when AC line voltage is lost. The supplied battery can provide approximately 24 hours of backup power.

The battery leads and connector are polarized. The positive (+) wire is RED, and the negative (-) wire is BLACK. This is important to note when connecting the battery to the main control board inside the PowerMonitor

Do not continue to use lithium ion/lithium polymer batteries that show signs of damage or will not hold a charge.

## DANGER !

Do not drop, throw, modify, or tamper with lithium-ion batteries.

Do not use batteries that are swollen, dented, or show other signs of damage.

Store and use batteries in a dry location at room temperature, away from direct sunlight and extreme temperatures.

Dispose of batteries properly through designated recycling programs.

Do not overcharge batteries and ensure they are charged in a wellventilated area, away from soft surfaces.

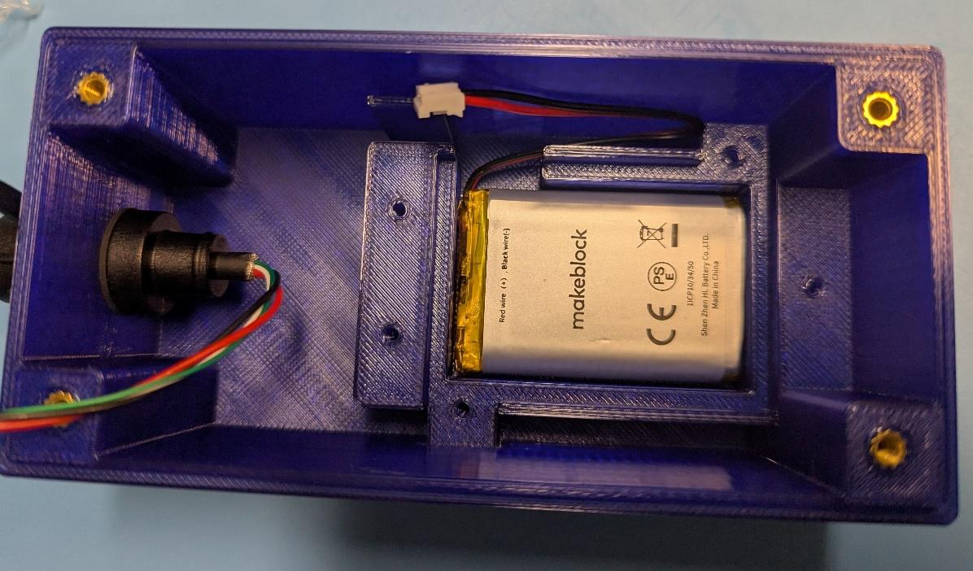
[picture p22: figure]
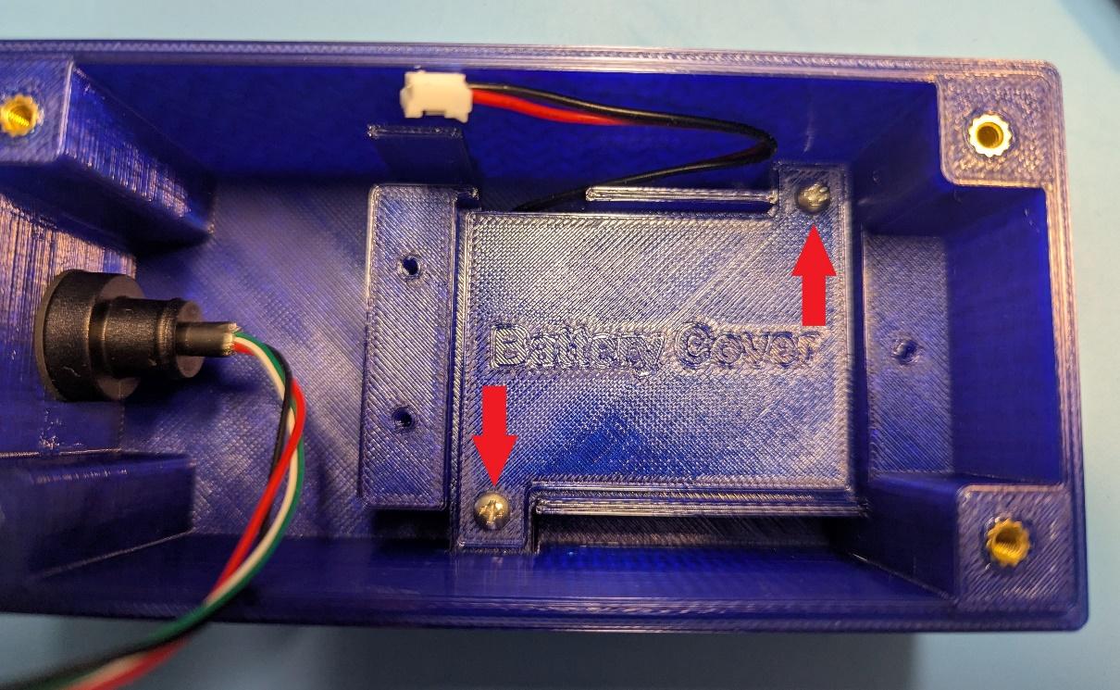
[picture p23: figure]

Cypress Embedded Systems | 10002-UM-001 rev. 1

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

14

Battery Installation

Figure 5 - Battery Compartment

The battery is located inside the enclosure as shown in Figure 5 - Battery Compartment.

Figure 6 - Battery Cover

The battery cover as shown in Figure 6 - Battery Cover is secured using two M3 x 10mm 18-8 stainless steel thread forming screws for plastic.

Cypress Embedded Systems | 10002-UM-001 rev. 1

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

15

## ! CAUTION

If the M3 x 10mm 18-8 stainless steel thread forming screws for plastic are removed care must be taken when reinstalling them to ensure that new threads are not cut into the plastic body of the enclosure. Failure to do this will result in damage to the enclosure which is not covered by warranty.

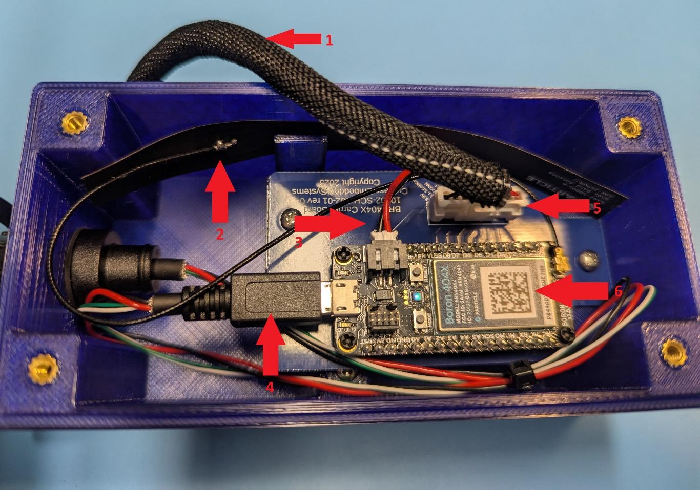
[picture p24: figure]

Cypress Embedded Systems | 10002-UM-001 rev. 1

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

16

Internal Device Features

Figure 7 - Internal Device Features

The internal features of the PowerMonitor device are as follows.

1 – LED indicator board wiring harness
2 – LTE cellular antenna
3 – Lithium polymer battery connector
4 – Main control board Micro-USB connector
5 – LED indicator wiring harness connector and header (to main control board)
6 – Particle Boron BRN404X main control board

The LTE cellular antenna has an adhesive backing which has not been used in order to facilitate easier access to the battery compartment. The enclosure has been designed with a retaining clip to hold the antenna against the enclosure side wall.

INFORMATION

The lithium polymer battery JST connector is polarized. The RED wire is positive (+), and the BLACK wire is negative (-).

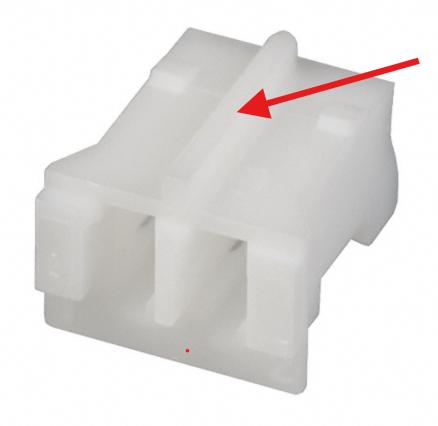
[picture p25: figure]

Cypress Embedded Systems | 10002-UM-001 rev. 1

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

17

Figure 8 - 2-Pole JST Battery Connector

The 2-pole JST connector is polarized and features a tab at the top of the housing that allows the connector to insert into the main control board only one way. This tab must be pointed upward.

## ! CAUTION

IMPORTANT:
The JST connector is polarized and only inserts in one way onto the main control board.

Note the orientation of the device body and of the JST connector shown in Figure 7 - Internal Device Features and ensure the RED positive (+) lead is on the right, and the BLACK negative (-) lead is on the left.

Not all batteries come with the connector attached in the correct polarity.

Failure to observe correct connector polarity will result in permanent damage to the main control board and to the battery.

The main control board is secured to the enclosure using three M3 x 10mm 18-8 stainless steel thread forming screws for plastic.

## ! CAUTION

If the M3 x 10mm 18-8 stainless steel thread forming screws for plastic are removed care must be taken when reinstalling them to ensure that new threads are not cut into the plastic body of the enclosure. Failure to do this will result in damage to the enclosure which is not covered by warranty.

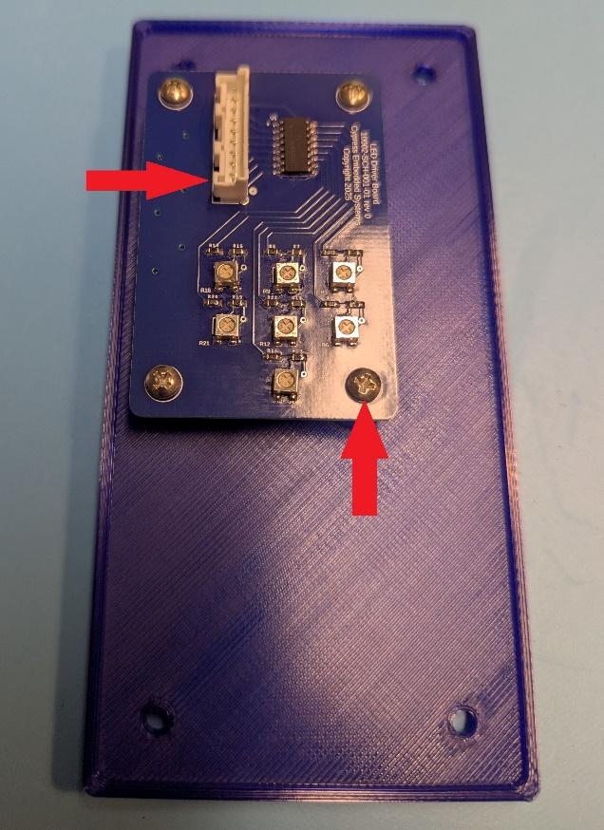
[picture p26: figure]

Cypress Embedded Systems | 10002-UM-001 rev. 1

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

18

Enclosure Cover – LED Driver Board

Figure 9 - LED Driver Board

The PowerMonitor cover holds the LED driver circuit that powers the LED indicators on the front cover.

The header on the LED driver circuit board connects to the opposite end of the wiring harness shown in Figure 7 - Internal Device Features.

The LED driver circuit board is secured to the cover using four M3 x 10mm 18-8 stainless steel thread forming screws for plastic.

## ! CAUTION

If the M3 x 10mm 18-8 stainless steel thread forming screws for plastic are removed care must be taken when reinstalling them to ensure that new threads are not cut into the plastic body of the enclosure. Failure to do this will result in damage to the enclosure which is not covered by warranty.

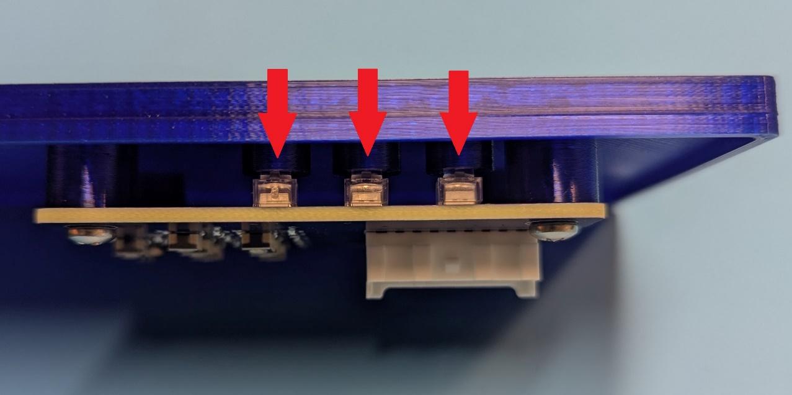
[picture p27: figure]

Cypress Embedded Systems | 10002-UM-001 rev. 1

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

19

INFORMATION

NOTE: The LED’s used are of the surface mounted type. LED light pipes are used to project the light from the LEDs to the front of the enclosure cover. These light pipes are loose fit and will fall off if the LED driver circuit board is removed from the cover. When reinstalling the light pipes note that there are bosses on them that match to mounting holes on the circuit board. See Figure 10 - LED Light Pipes.

Figure 10 - LED Light Pipes

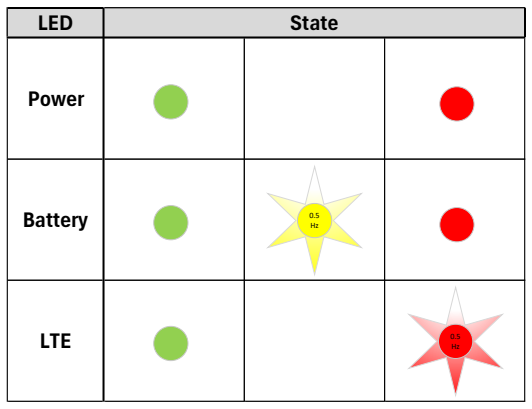
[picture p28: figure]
LED; State; Power; Battery; LTE
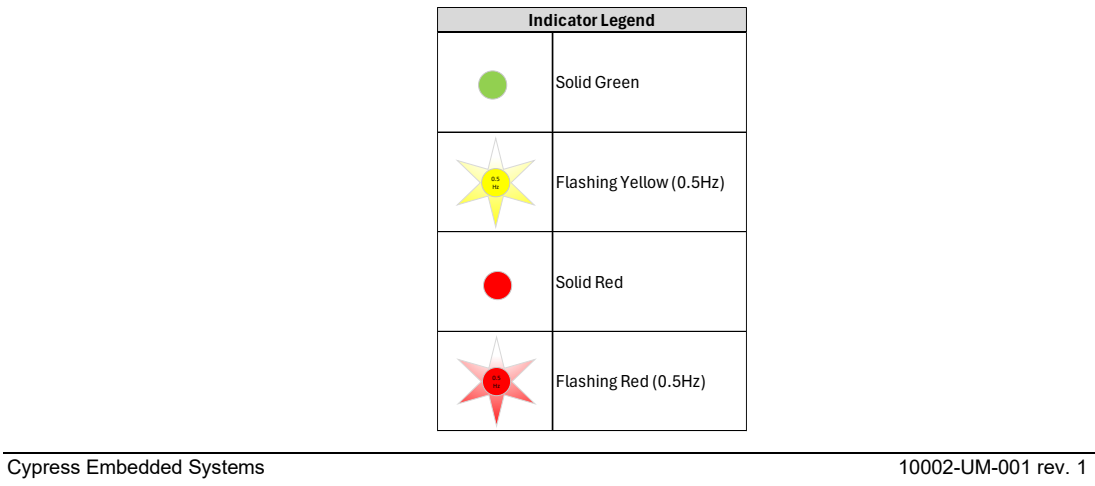
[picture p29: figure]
Cypress Embedded Systems; 10002-UM-001 rev. 1; Solid Green; Flashing Yellow (0.5Hz); Solid Red; Flashing Red (0.5Hz); Indicator Legend

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

20

## Functionality

The PowerMonitor is designed to provide users push notifications to their smartphones when AC line voltage is lost or restored.

INFORMATION

For the device to function properly, make sure the device DC power adaptor is plugged into a 120Vac power outlet.

Ensure that the power outlet is not protected with a battery backup system such as an Uninterruptible Power Supply (UPS).

### LED Indicators

The LED indicators provide users with valuable status information about the condition of the PowerMonitor device.

Table 1 - LED State Colors

Table 2 - LED State Color Legend

Cypress Embedded Systems | 10002-UM-001 rev. 1

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

21

The following describes the meaning of each LED indicator.

Power
When the PowerMonitor is operating on AC line voltage this LED will be solid green in color. When AC line voltage is lost the LED indicator will turn solid red.

Battery
When the internal lithium polymer battery is fully charged the LED indicator will be solid green in color. If the battery is charging, the LED indicator will flash at a frequency of 0.5Hz and will be yellow in color. If there is a problem with the battery the LED indicator will be solid red in color.

Note that when the PowerMonitor is running from the backup battery, the Battery LED will not be on unless there is a battery fault.

If the Battery LED is red, this indicates that there is a problem with the battery. The following are conditions that can cause a battery fault.

Battery State Unknown
Battery Not Charging
Battery Fault
Battery Not Connected

If a fault exists, check to ensure that the battery is connected to the main control board. Alternatively, if the PowerMonitor has been in service for a long period of time, open the battery cover and inspect the battery. If the battery is puffy or appears deformed, not holding a charge (low voltage after being charged for a long time), disconnect the battery and dispose of it in an appropriate manner. Replace the battery.

Do not continue to use lithium ion/lithium polymer batteries that show signs of damage or will not hold a charge.

Replacement batteries can be purchased from Cypress Embedded Systems. Contact mike@cypressembeddedsystems.ca. Alternatively, a replacement battery can be purchased directly from https://ca.robotshop.com/.

INFORMATION

Nominal battery voltage is 3.7Vdc. A fully charged battery should be approximately 4.2Vdc.

The normal operating range of the battery is 3.2Vdc minimum to 4.2Vdc maximum.

Cypress Embedded Systems | 10002-UM-001 rev. 1

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

22

LTE
When the PowerMonitor is connected to both cellular LTE and the Particle.IO cloud service, the LED will be solid green. When the device first powers on, the LED will be solid red until cellular LTE and Particle.IO cloud service is connected.

While the PowerMonitor is running it checks to verify that it is still connected to both cellular LTE and the Particle.IO cloud service every 60 seconds. If either service is lost, the LTE LED will flash red at a frequency of 0.5Hz until these services are reconnected.

INFORMATION

No push notifications will be received if there is no connection to cellular LTE and Particle.IO cloud services.

If you are unable to connect to the cellular network, try moving the PowerMonitor to a different location. This device will work in most basements; however, try to keep the device out of areas where a cellular network signal may become attenuated such as areas with lots of concrete.

INFORMATION

The following links provide cellular coverage maps for Bell Canada, Telus Mobility, and Rogers. The PowerMonitor uses LTE Cat M1 for IoT devices.

https://www.bell.ca/Mobility/Our_network_coverage

https://www.rogers.com/mobility/network-coverage-map

https://www.telus.com/en/mobility/network/coverage-map

INFORMATION

The area and environment where your PowerMonitor is installed influences cellular signal strength and quality.

If you have installed the PowerMonitor in an area that has a weak cellular signal you may show being connected to LTE on the device, but data may not get transmitted. Push notifications may not be received. If your cellular phone shows a weak signal this can possibly confirm this scenario.

If moving the device to another area is unsuccessful, consider installing a cellular signal booster. These are available at various online retailers such as Amazon. When selecting one, ensure it has support for Bell, Rogers, and Telus, and for cellular LTE bands 2, 4, 5, 12, and 13.

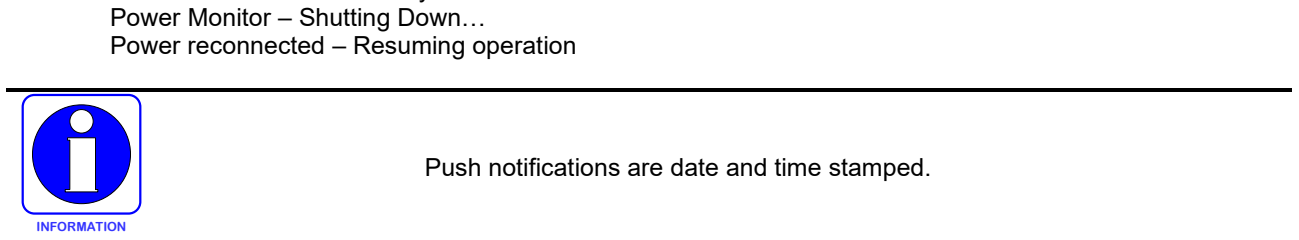
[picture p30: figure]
Power Monitor – Shutting Down… Power reconnected – Resuming operation; INFORMATION

Cypress Embedded Systems | 10002-UM-001 rev. 1

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

23

### Push Notifications

Users of the PowerMonitor are required to have the Pushover application installed and running on their smartphone. Installation and configuration of the Pushover application are outside the scope of this document.

The following are the push notifications that the PowerMonitor provides.

Initial Power Up:
Application booting… AC POWER GOOD
Application booting… NO AC POWER

When the PowerMonitor is first powered on, one of the above push notifications will be received.

Normal Operation:
Power Monitor – AC POWER LOST
Power Monitor – AC POWER IS ON

Under normal operating conditions, one of the above push notifications will be received upon loss or restoration of AC line voltage.

Battery Status – Fault Conditions:
Battery State Unknown
Battery Not Charging
Battery Fault
Battery Disconnected

If there is an issue with the internal lithium polymer backup battery, one of the above push notifications may be received. Battery issues should be addressed at the earliest possible opportunity.

Low Battery Power:
Power Monitor – Low Battery

Push notifications are date and time stamped.

The PowerMonitor device measures the internal battery voltage while it is operating on battery backup. If the battery’s voltage drops below a minimum threshold a push notification will is sent to the user warning that such a condition exists. Shortly after this message is sent the PowerMonitor device will shut itself down to protect the unit from an undervoltage condition that can permanently damage the battery.

If AC line voltage is restored while in the process of shutting down, the shutdown procedure will halt and normal operation will resume; otherwise, the unit shuts down and will only power back on when AC line voltage is restored.

Cypress Embedded Systems | 10002-UM-001 rev. 1

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

24

The PowerMonitor device handles the charging of the internal lithium battery while AC line voltage is present. The device will charge the battery and maintain a charged state. Internal power management circuitry prevents the battery from overcharging.

User Manual | May 2025
Cypress Embedded Systems | 10002-UM-001 rev. 1

©2025 Michael McMahon, Cypress Embedded Systems. All rights reserved. This work is licensed under a Creative Commons Attribution-NonCommercial-ShareAlike 4.0 International License. You should have
| received a copy of the license along with this work. If not, see http://creativecommons.org/licenses/by-nc-sa/4.0/.

25

## Technical Specifications

Enclosure | NEMA Type 1 / IP10 equivalent custom 3D printed enclosure (Spectrum Filaments FlameGuard ASA 275).
PowerMonitor Input Power | Input power via microUSB connector; 5Vdc, 500mA maximum.
DC Power Supply | Input: 120Vac Output: 5Vdc, 3000mA
Cellular | Embedded EtherSIM for LTE Cat M1 North America (bands 2, 4, 5, 12, 13) Device to use supplied antenna only. Device is certified for use with the supplied antenna only.

Canada Statement: This device complies with Industry Canada’s licence-exempt RSSs. Operation is subject to the following two conditions:

1. This device may not cause interference; and
2. This device must accept any interference, including interference that may cause undesired operation of the device.
Le présent appareil est conforme aux CNR d’Industrie Canada applicables aux appareils radio exempts de licence.

L’exploitation est autorisée aux deux conditions suivantes:

1. l’appareil ne doit pas produire de brouillage;
2. l’utilisateur de l’appareil doit accepter tout brouillage radioélectrique subi, même si le brouillage est susceptible d’en compromettre le fonctionnement.

Caution Exposure: This device meets the exemption from the routine evaluation limits in section 2.5 of RSS102 and users can obtain Canadian information on RF exposure and compliance. Le dispositif répond à l'exemption des limites d'évaluation de routine dans la section 2.5 de RSS102 et les utilisateurs peuvent obtenir des renseignements canadiens sur l'exposition aux RF et le respect.

The final end product must be labelled in a visible area with the following: The Industry Canada certification label of a module shall be clearly visible at all times when installed in the host device, otherwise the host device must be labelled to display the Industry Canada certification number of the module, preceded by the words “Contains transmitter module”, or the word “Contains”, or similar wording expressing the same meaning, as follows:

Contains transmitter module ISED: 20127-BRN404X

This End equipment should be installed and operated with a minimum distance of 20 centimeters between the radiator and your body. Cet équipement devrait être installé et actionné avec une distance minimum de 20 centimètres entre le radiateur et votre corps.

The end user manual shall include all required regulatory information/warning as shown in this manual.

Refer to the following website for further details about this module: https://docs.particle.io/reference/datasheets/b-series/brn404x-datasheet/

Particle Boron BRN404X

Cypress Embedded Systems | 10002-UM-001 rev. 1

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

26

## Drawings

The following pages include dimensional drawings for:

i. Enclosure body
ii. | Enclosure lid
iii. | Battery compartment cover
iv. | LED driver board
v. Main control board

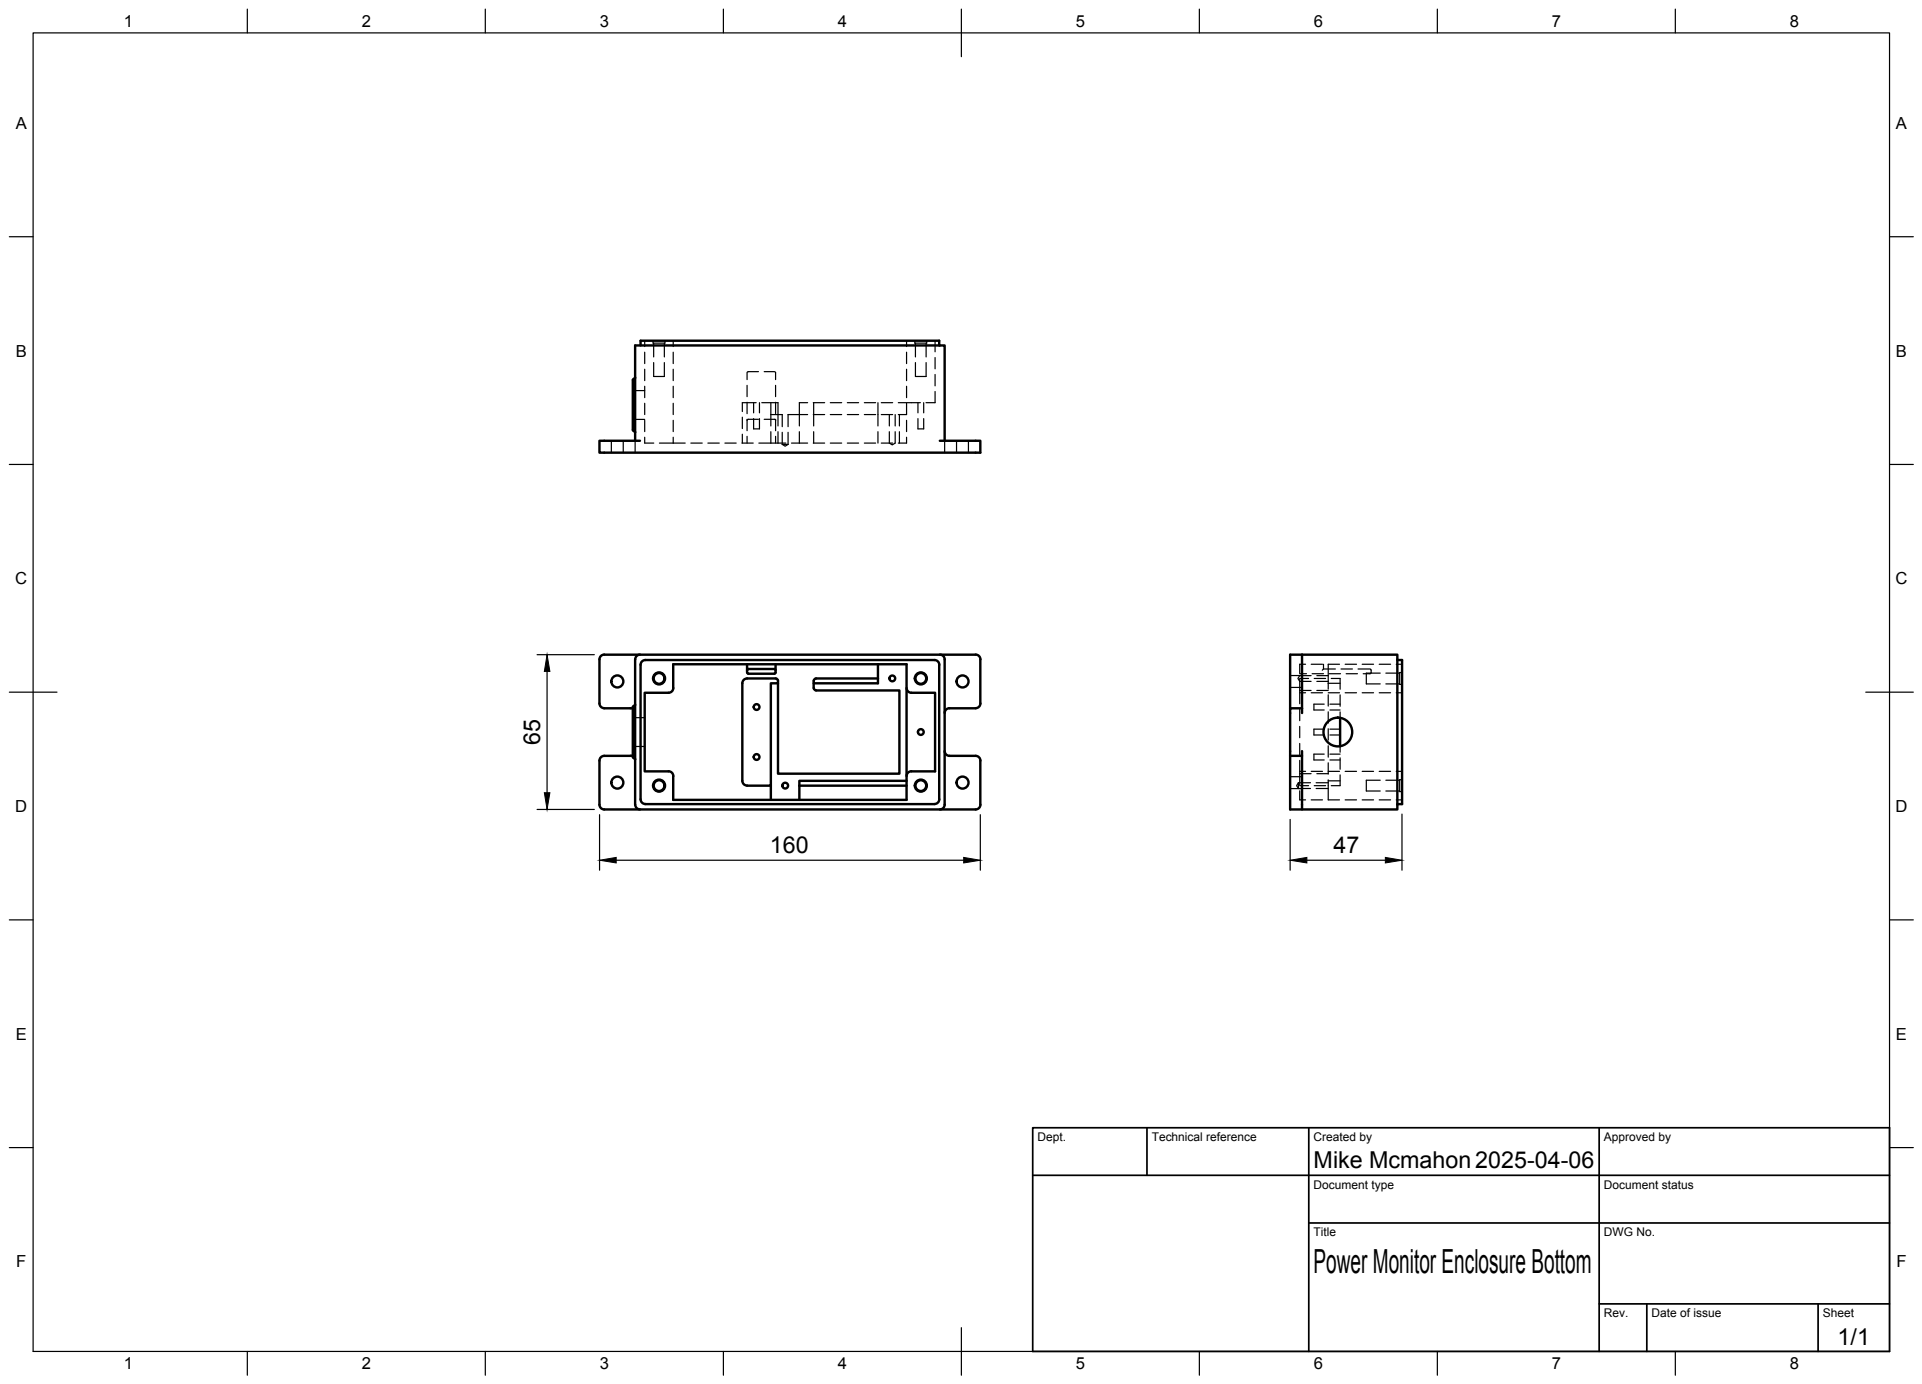
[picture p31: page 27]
Dept.; Technical reference; Created by; Approved by; Document type; Document status; Title; DWG No.; Rev.; Date of issue; Sheet; Mike Mcmahon

Power Monitor Enclosure Bottom

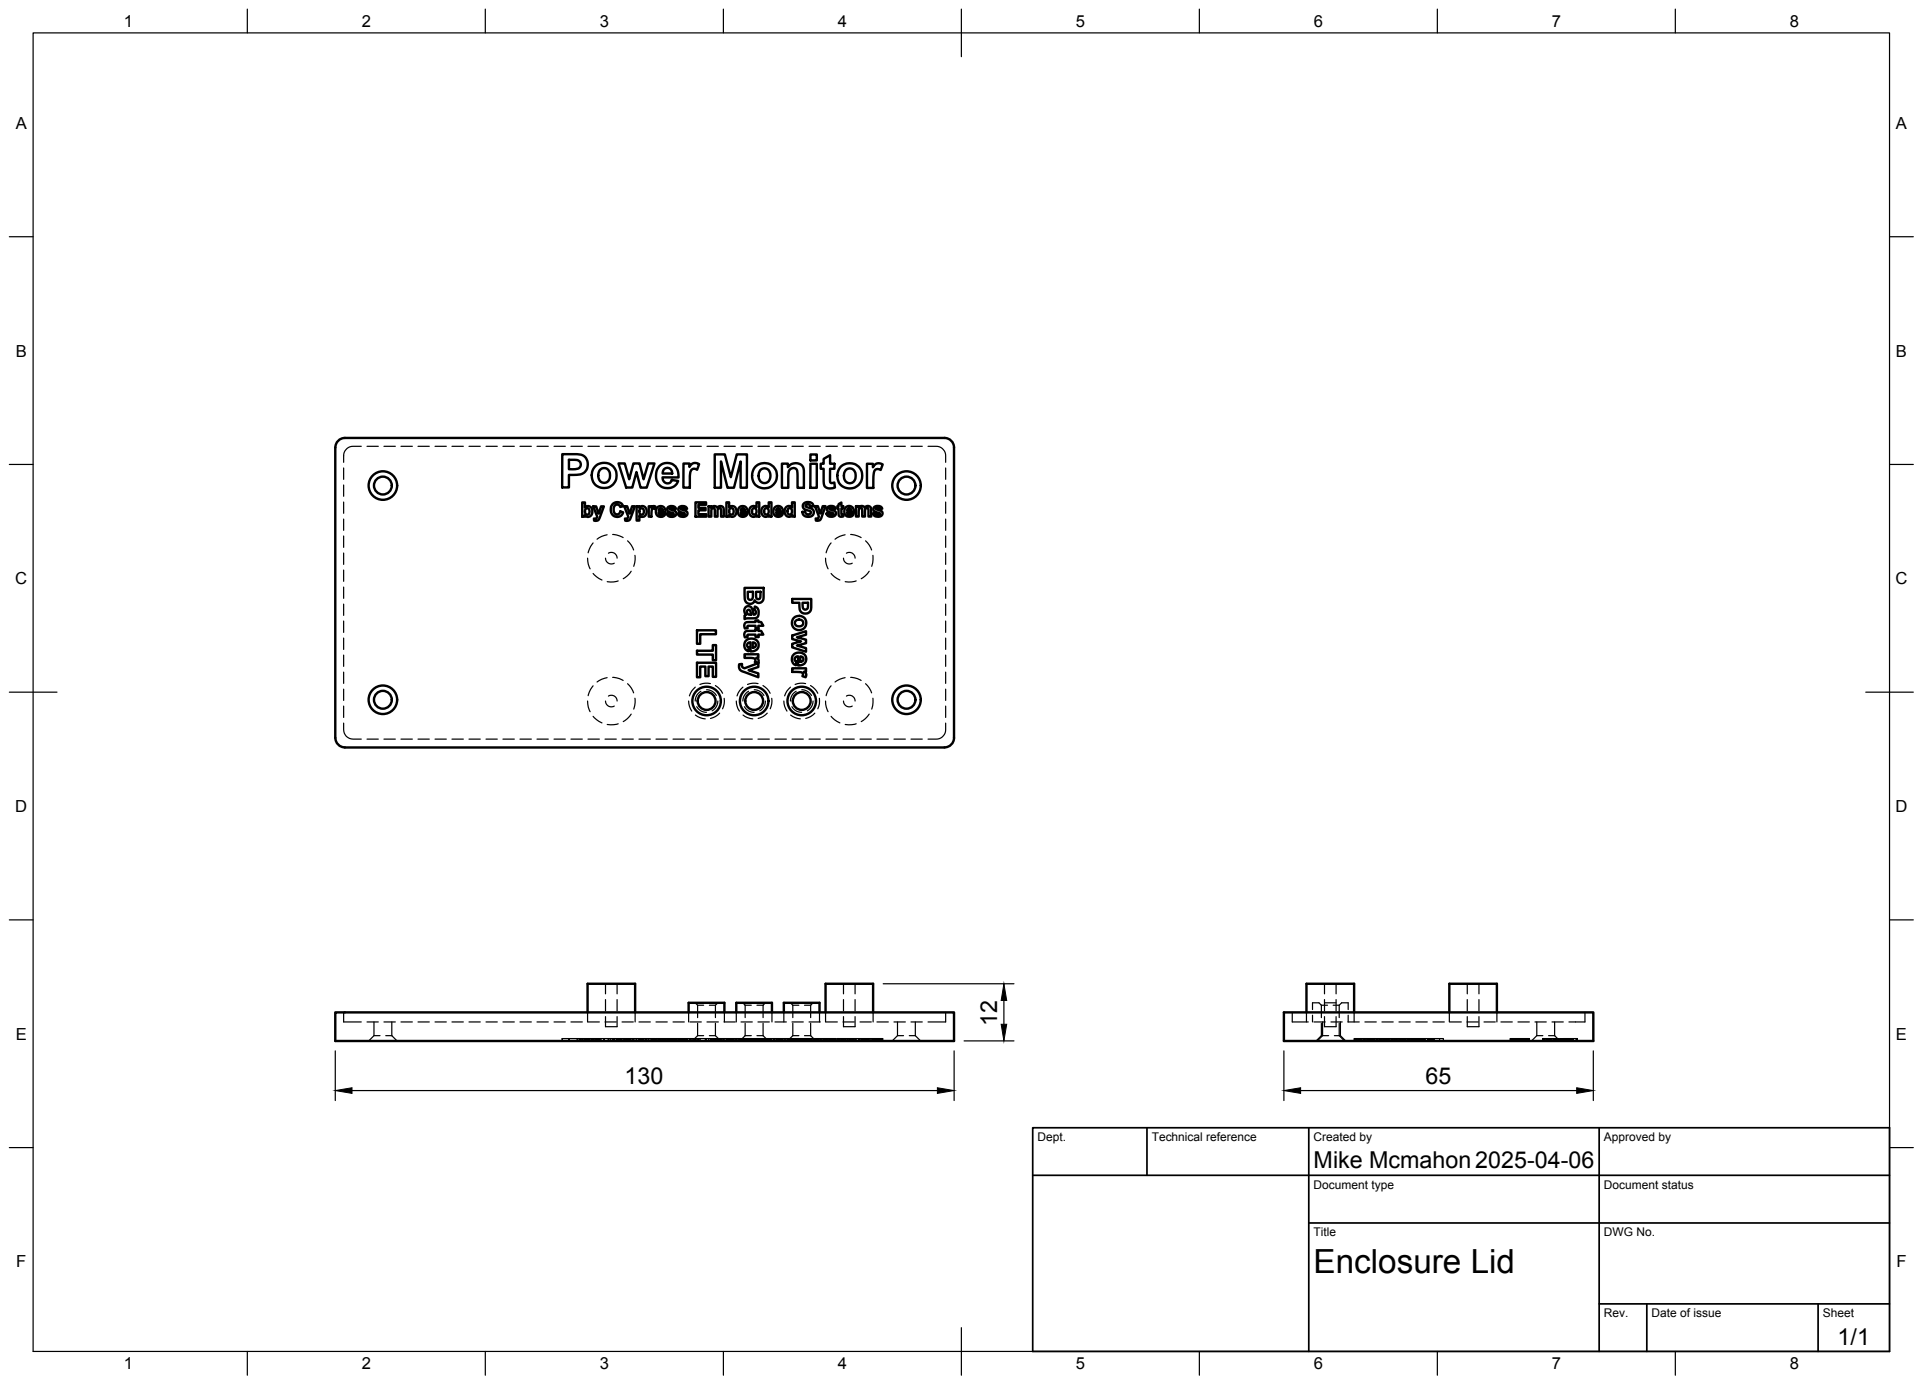
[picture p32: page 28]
Dept.; Technical reference; Created by; Approved by; Document type; Document status; Title; DWG No.; Rev.; Date of issue; Sheet; Enclosure Lid; Mike Mcmahon

55

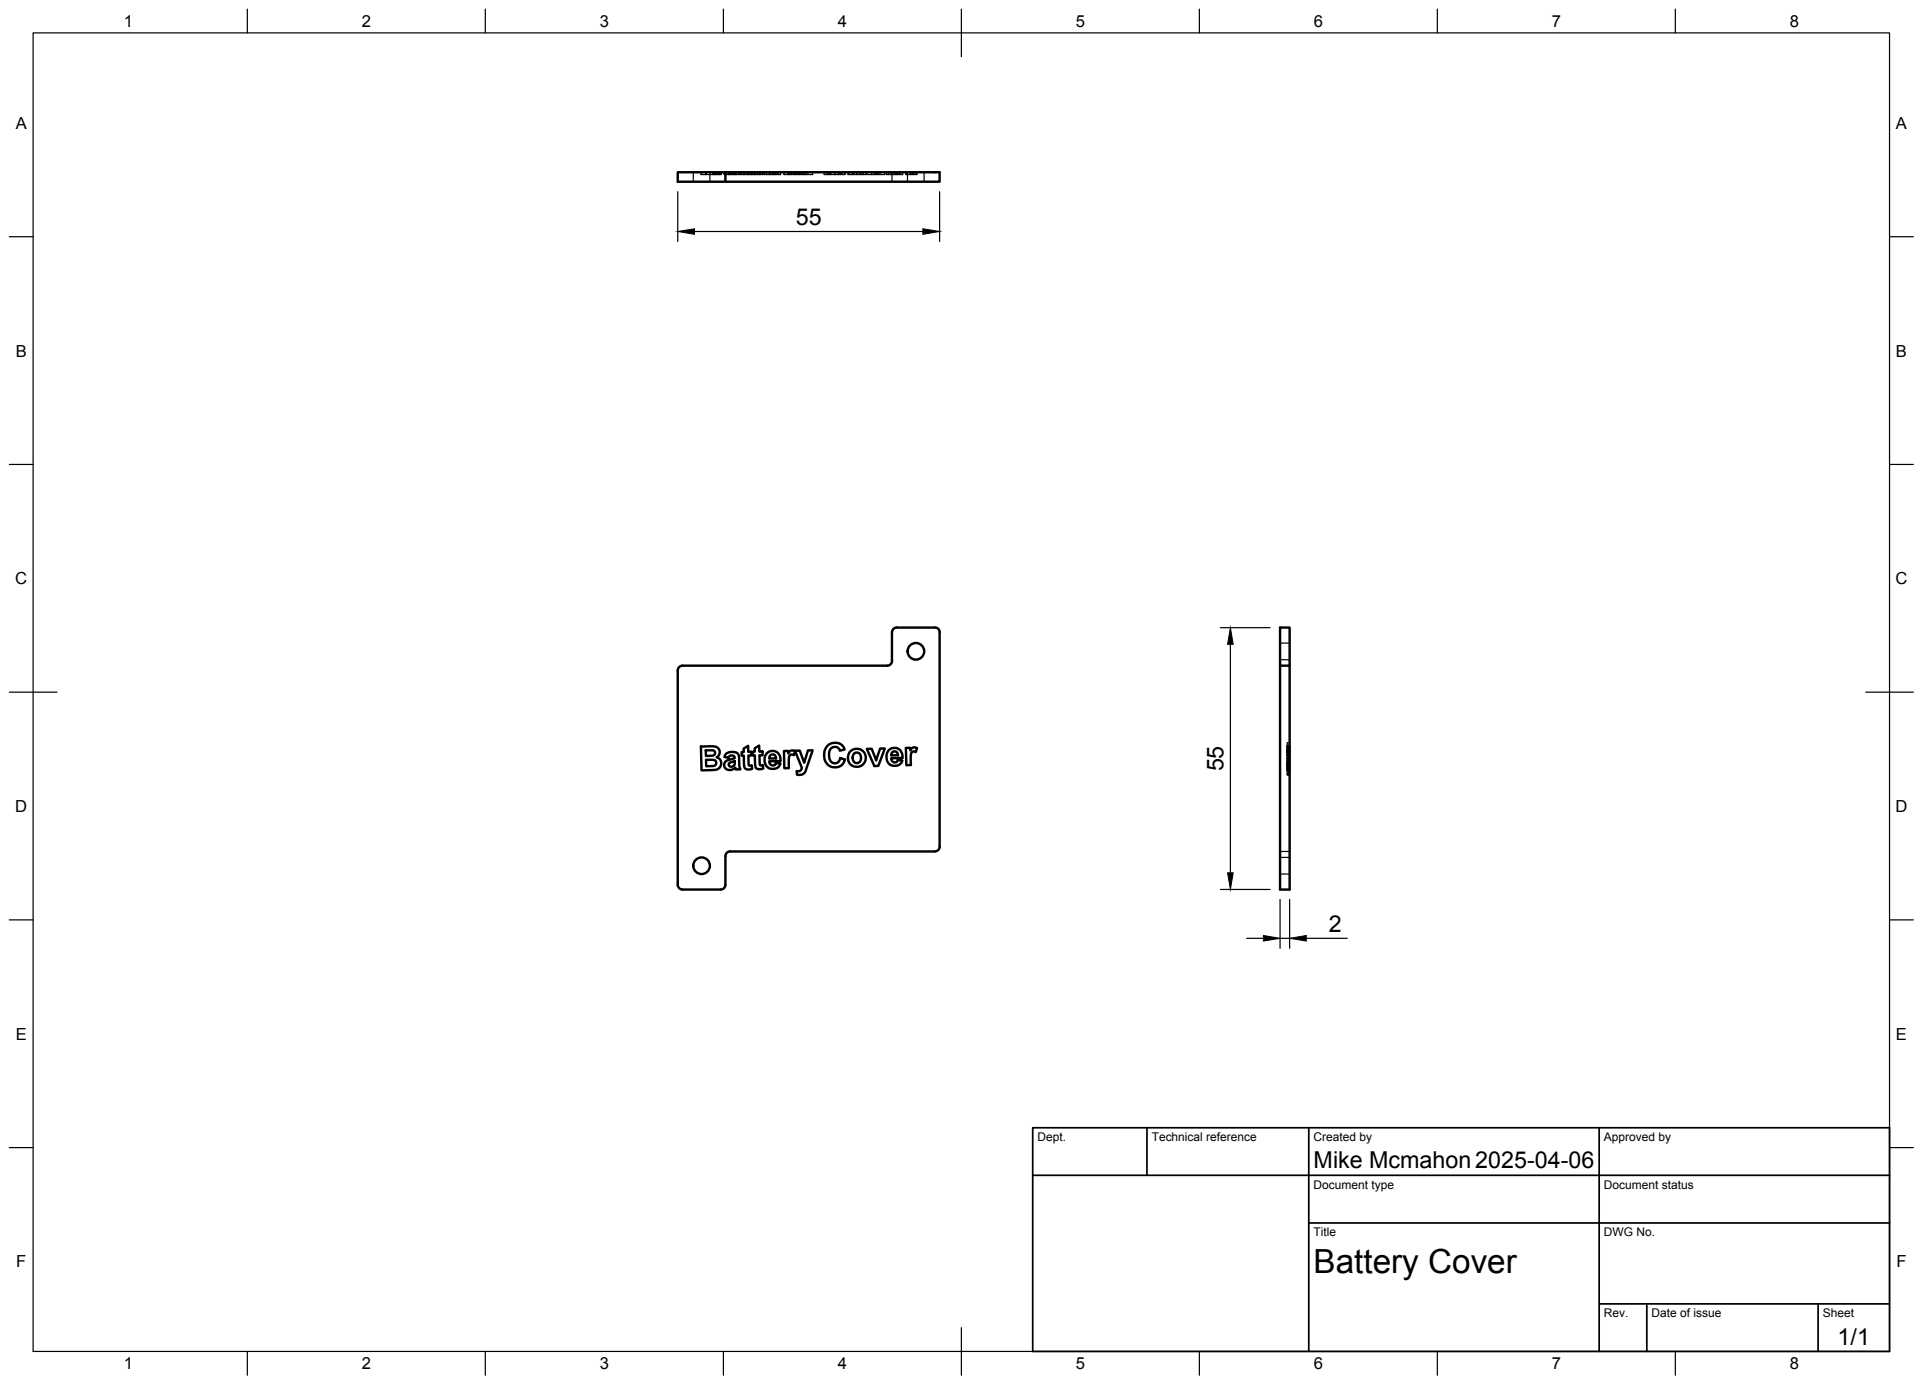
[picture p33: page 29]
Dept.; Technical reference; Created by; Approved by; Document type; Document status; Title; DWG No.; Rev.; Date of issue; Sheet; Battery Cover

Mike Mcmahon ⁵⁵

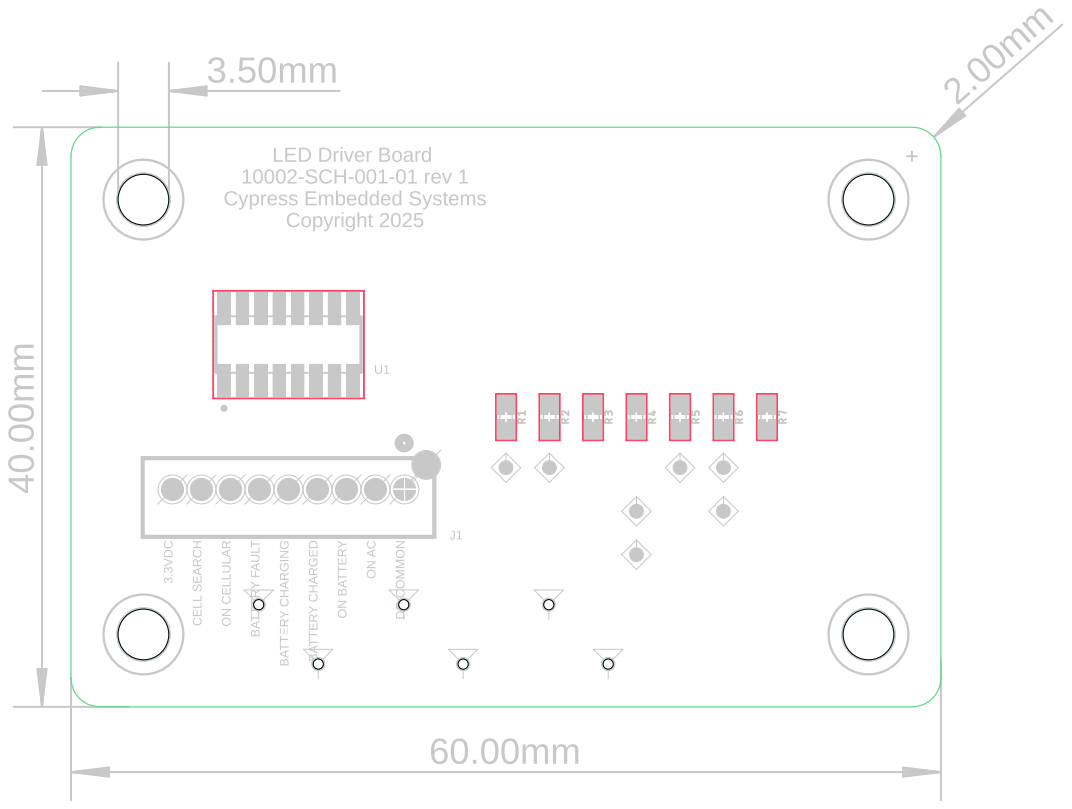
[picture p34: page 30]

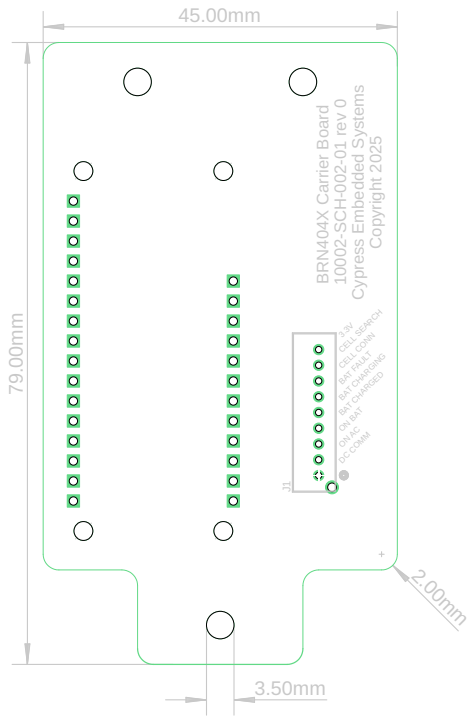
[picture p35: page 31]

3.3V CEL SEARCH CEL CONN BAT FAULT BAT CHARGING BAT CHARGED ON BAT ON AC DC COMM BRN404X Carrier Board 10002-SCH-002-01 rev 0 Cypress Embedded Systems Copyright 2025 45.00mm 79.00mm 3.50mm 2.0 mm J1

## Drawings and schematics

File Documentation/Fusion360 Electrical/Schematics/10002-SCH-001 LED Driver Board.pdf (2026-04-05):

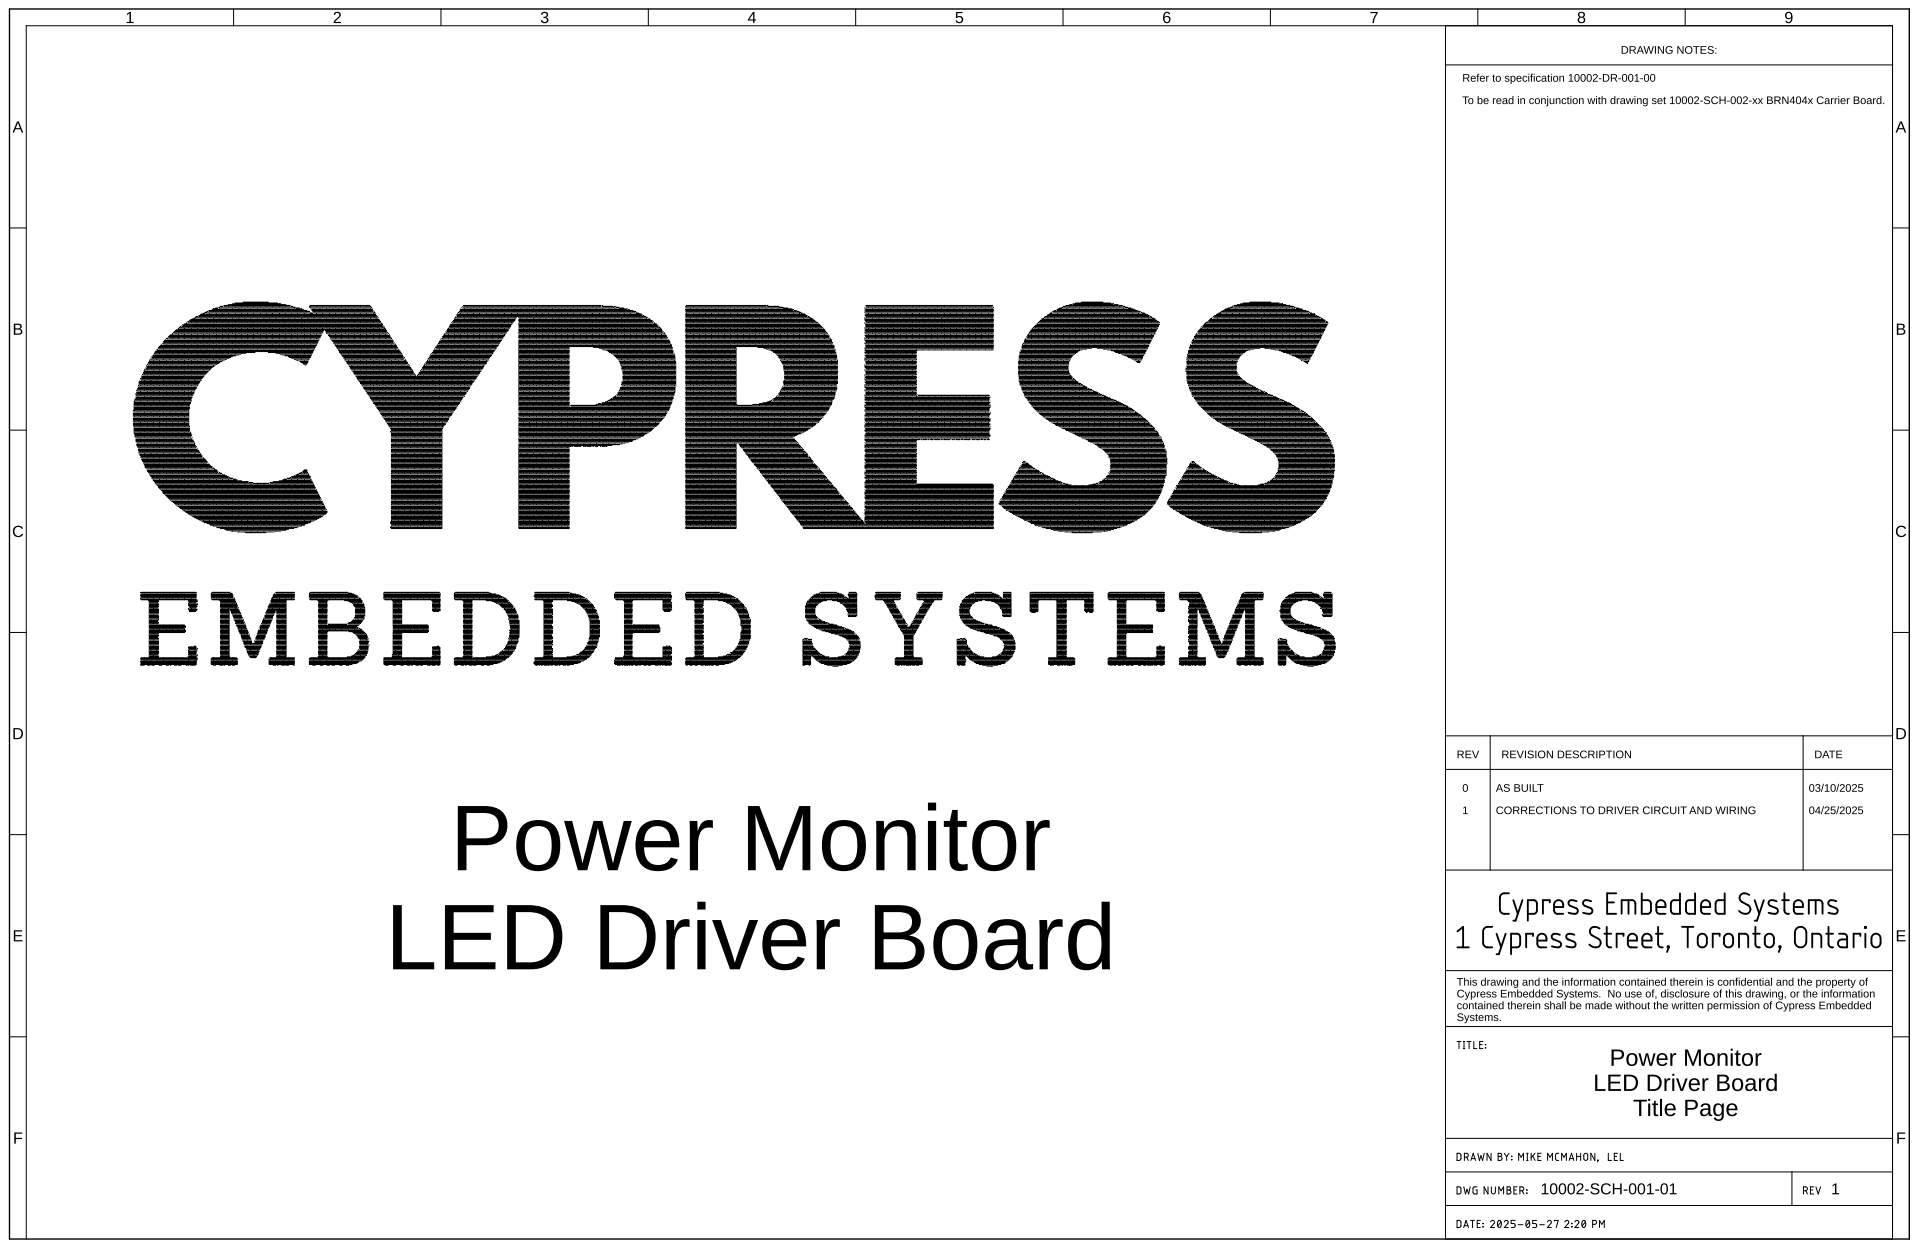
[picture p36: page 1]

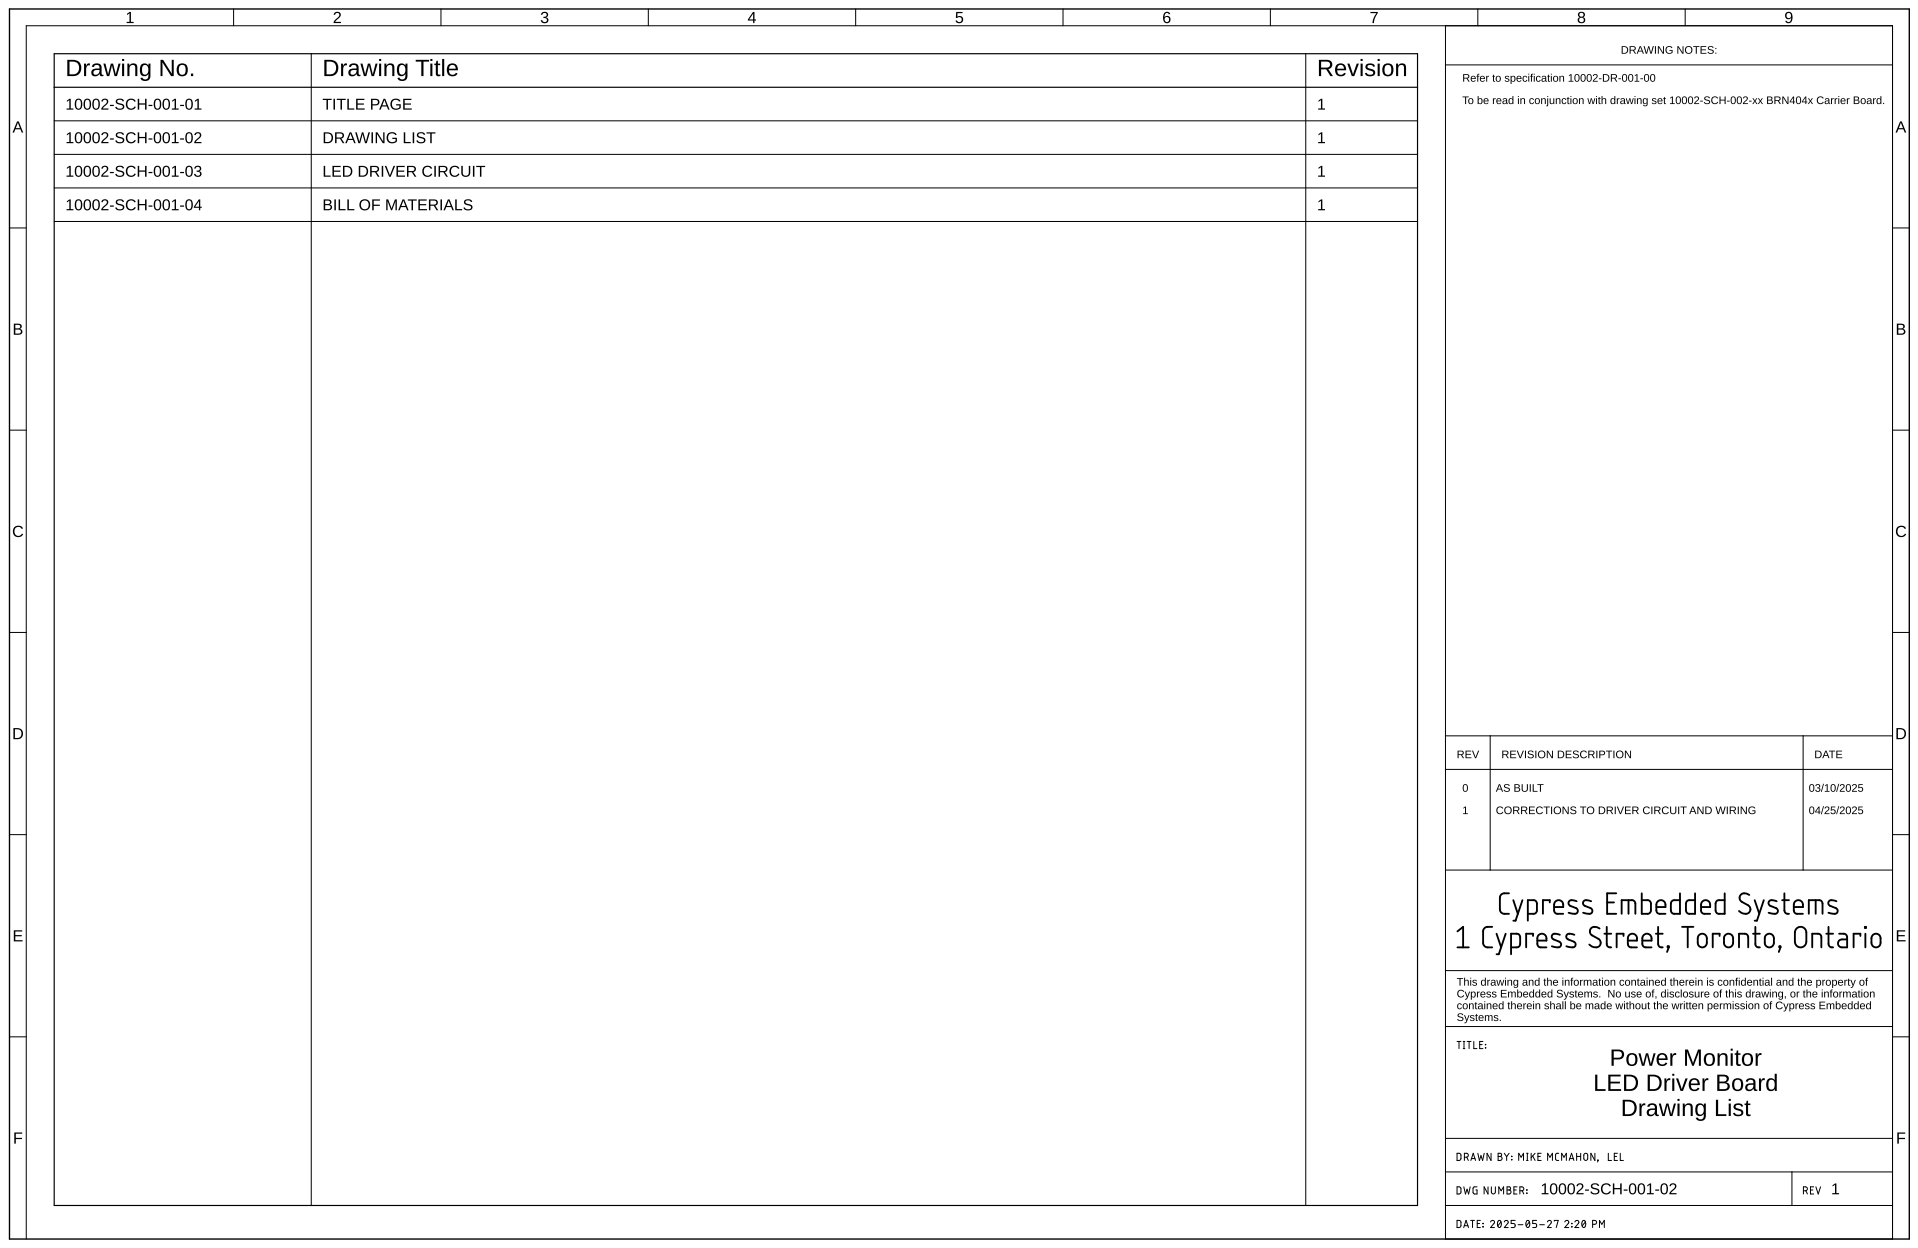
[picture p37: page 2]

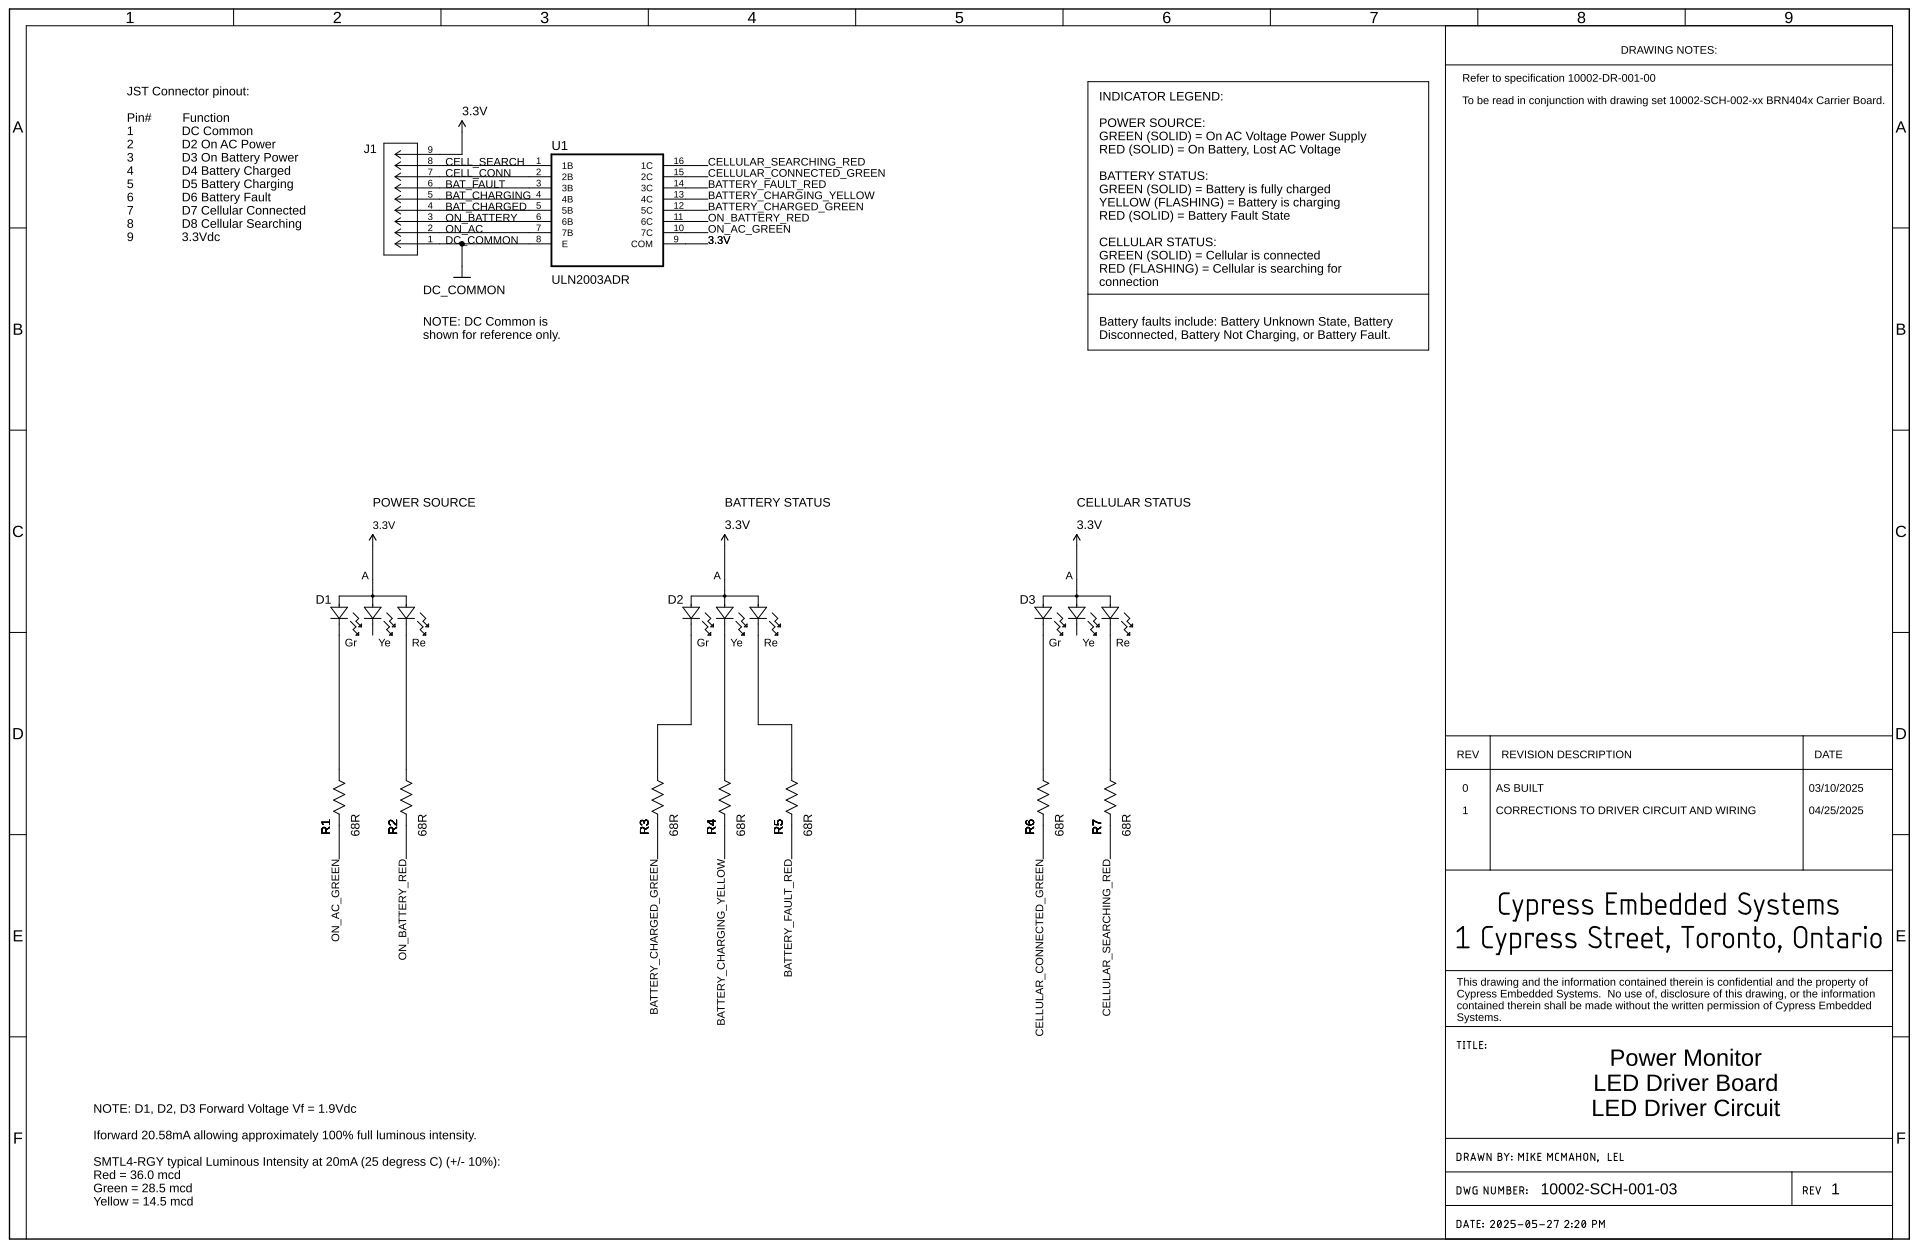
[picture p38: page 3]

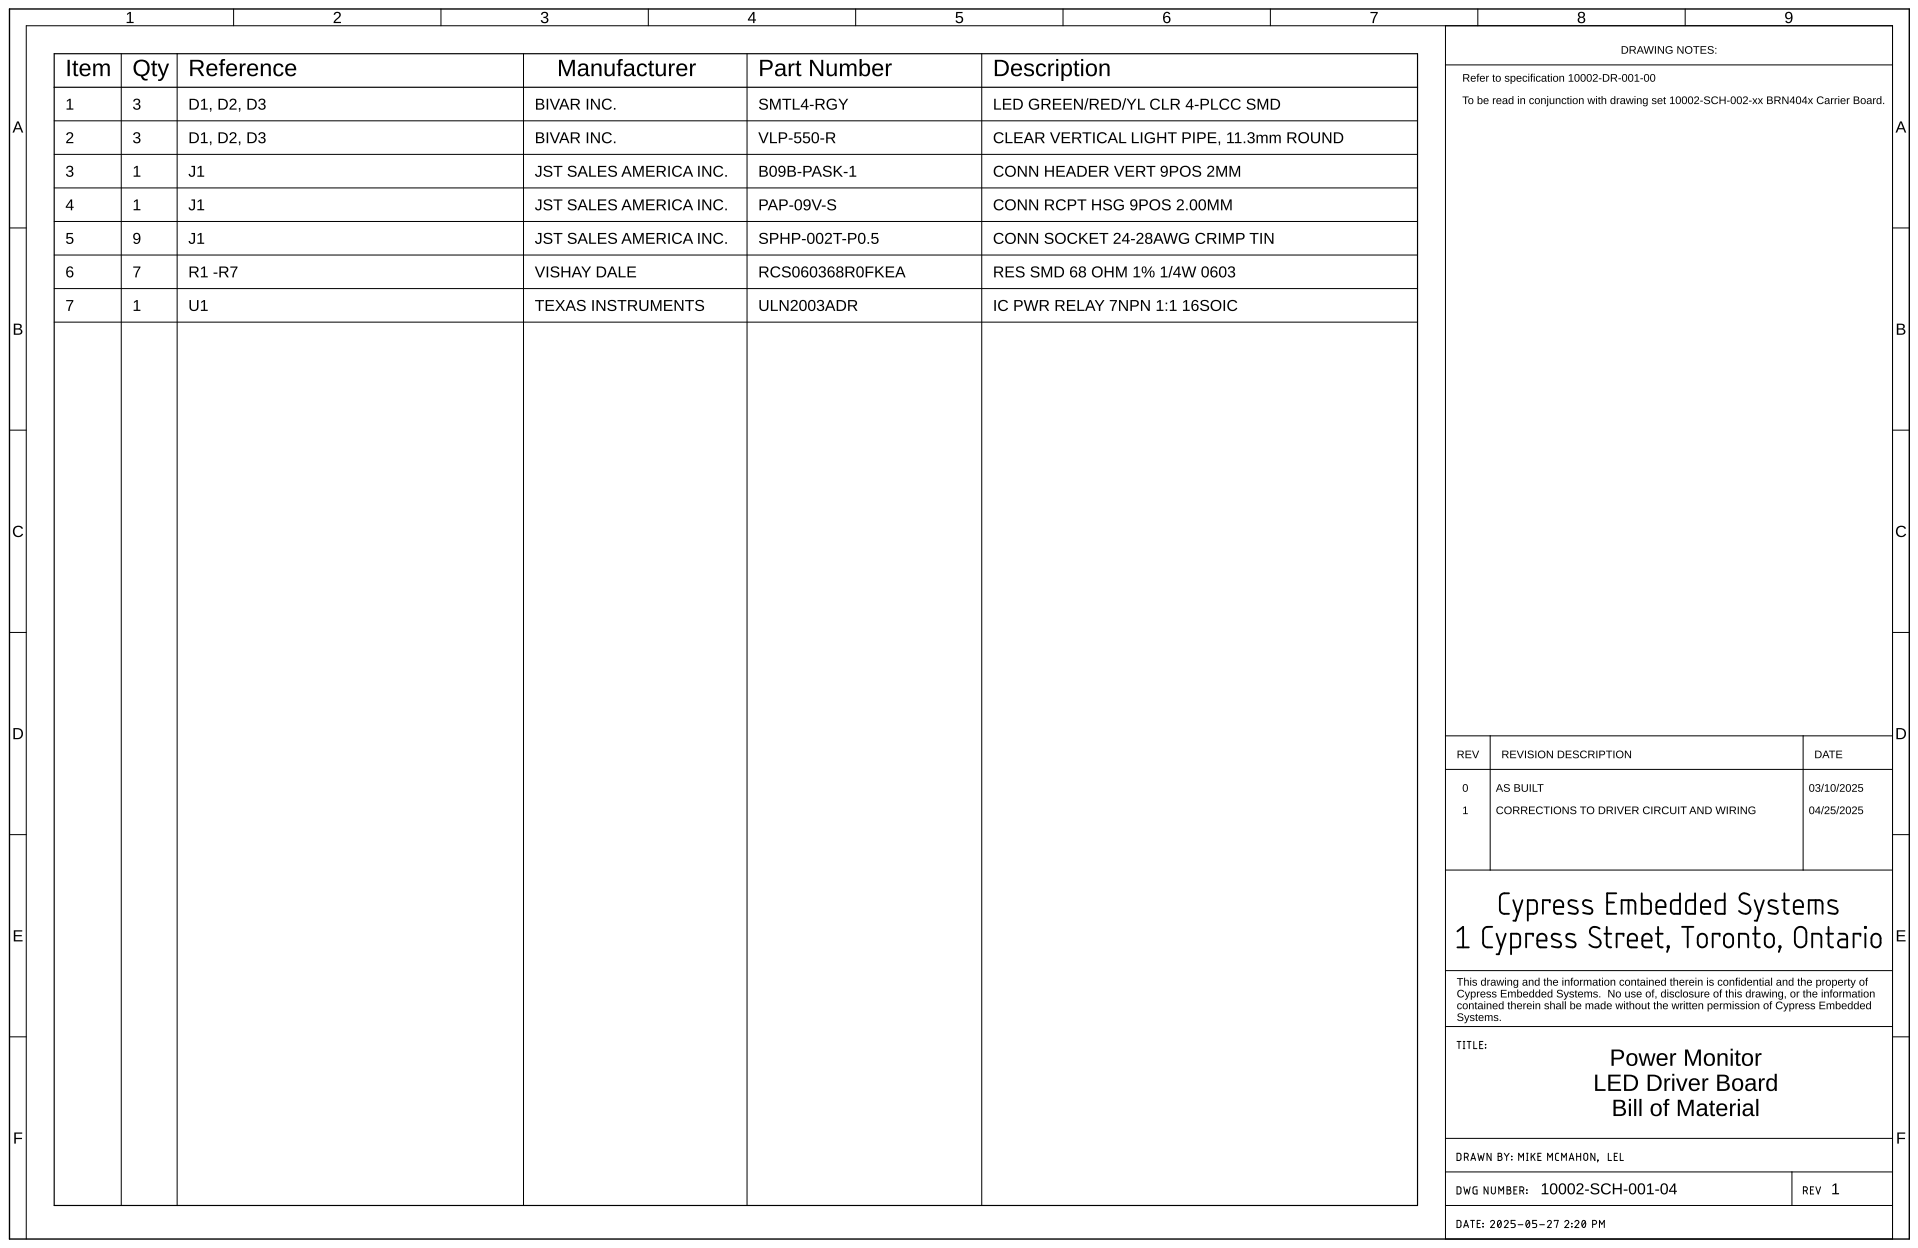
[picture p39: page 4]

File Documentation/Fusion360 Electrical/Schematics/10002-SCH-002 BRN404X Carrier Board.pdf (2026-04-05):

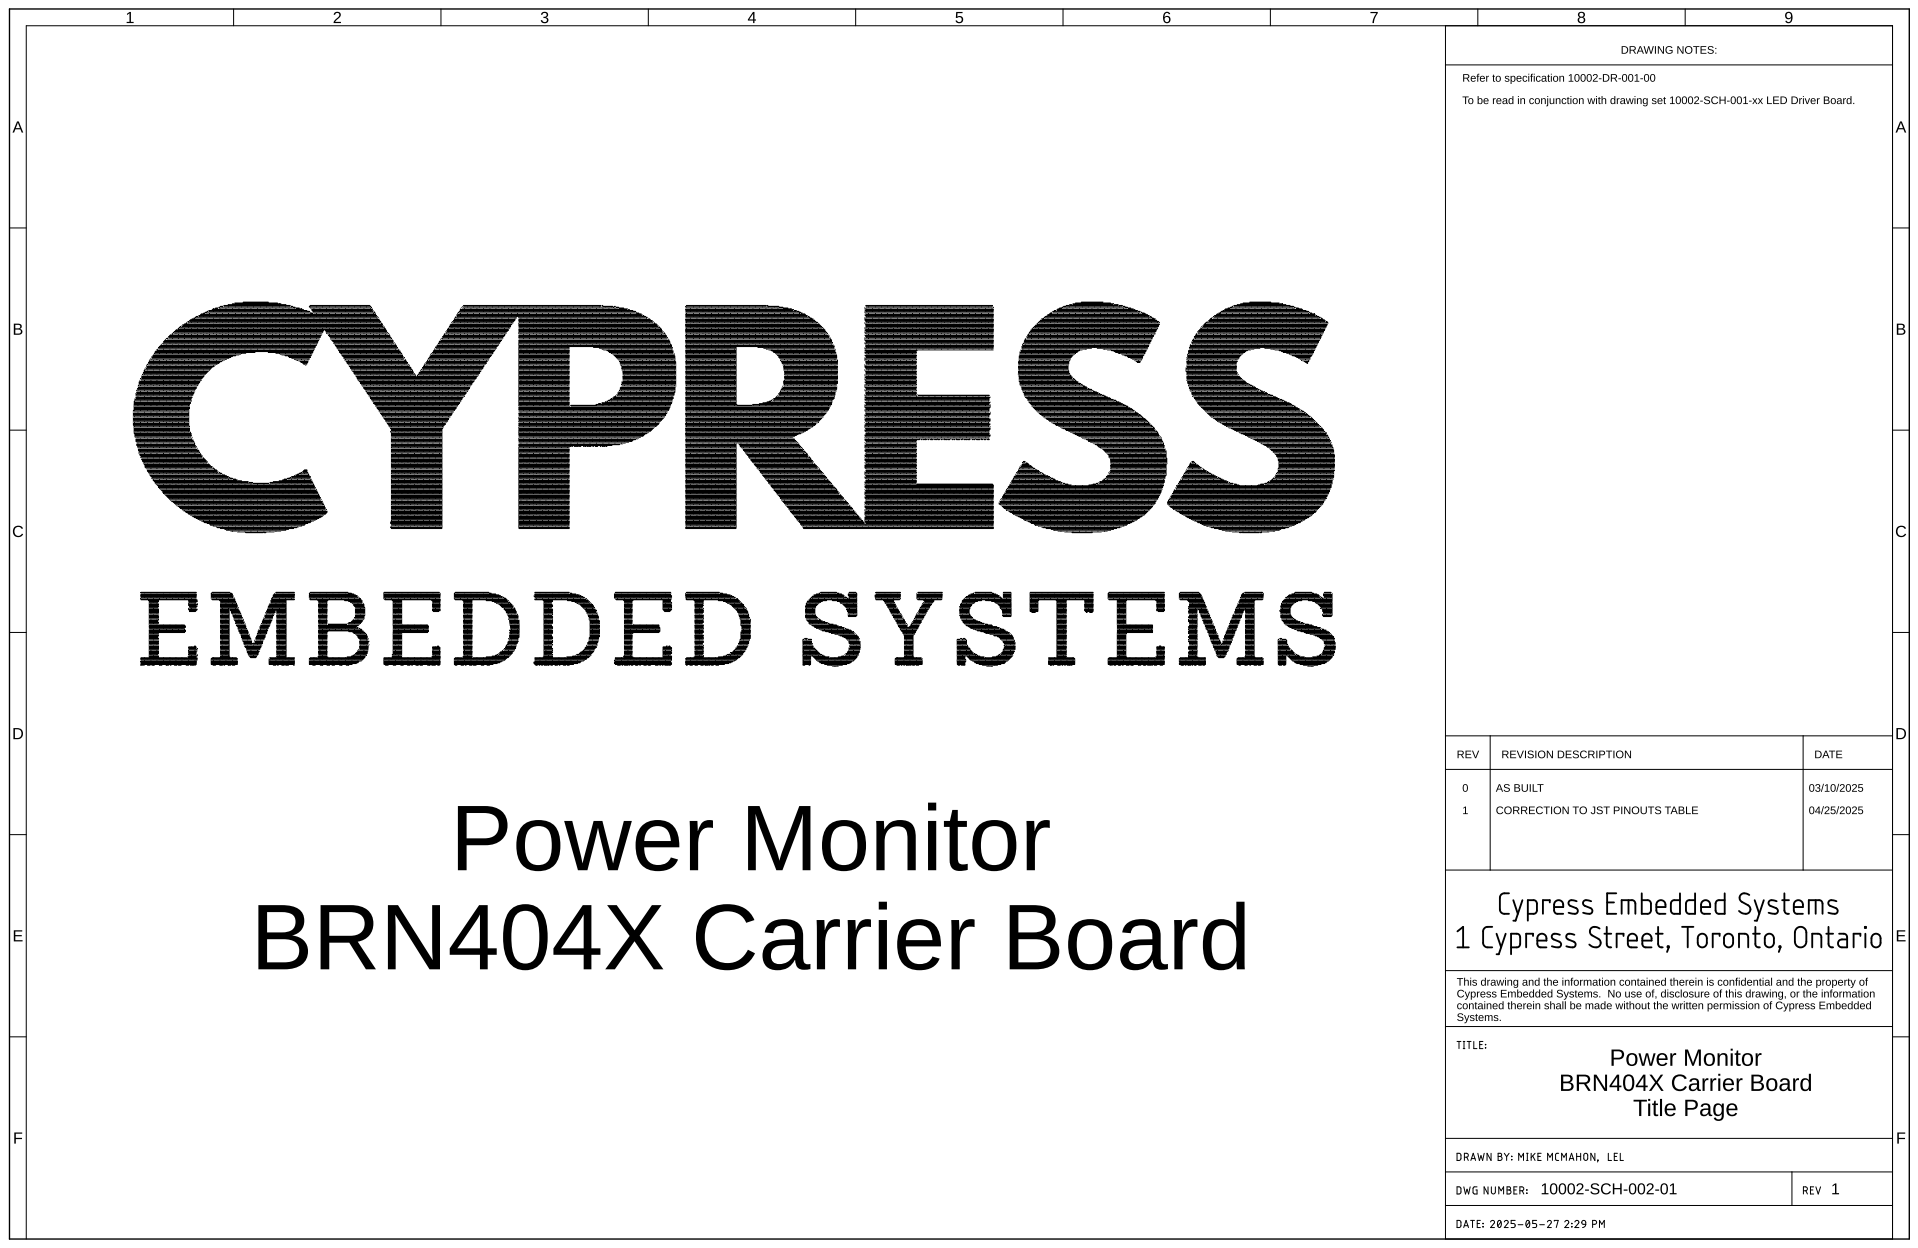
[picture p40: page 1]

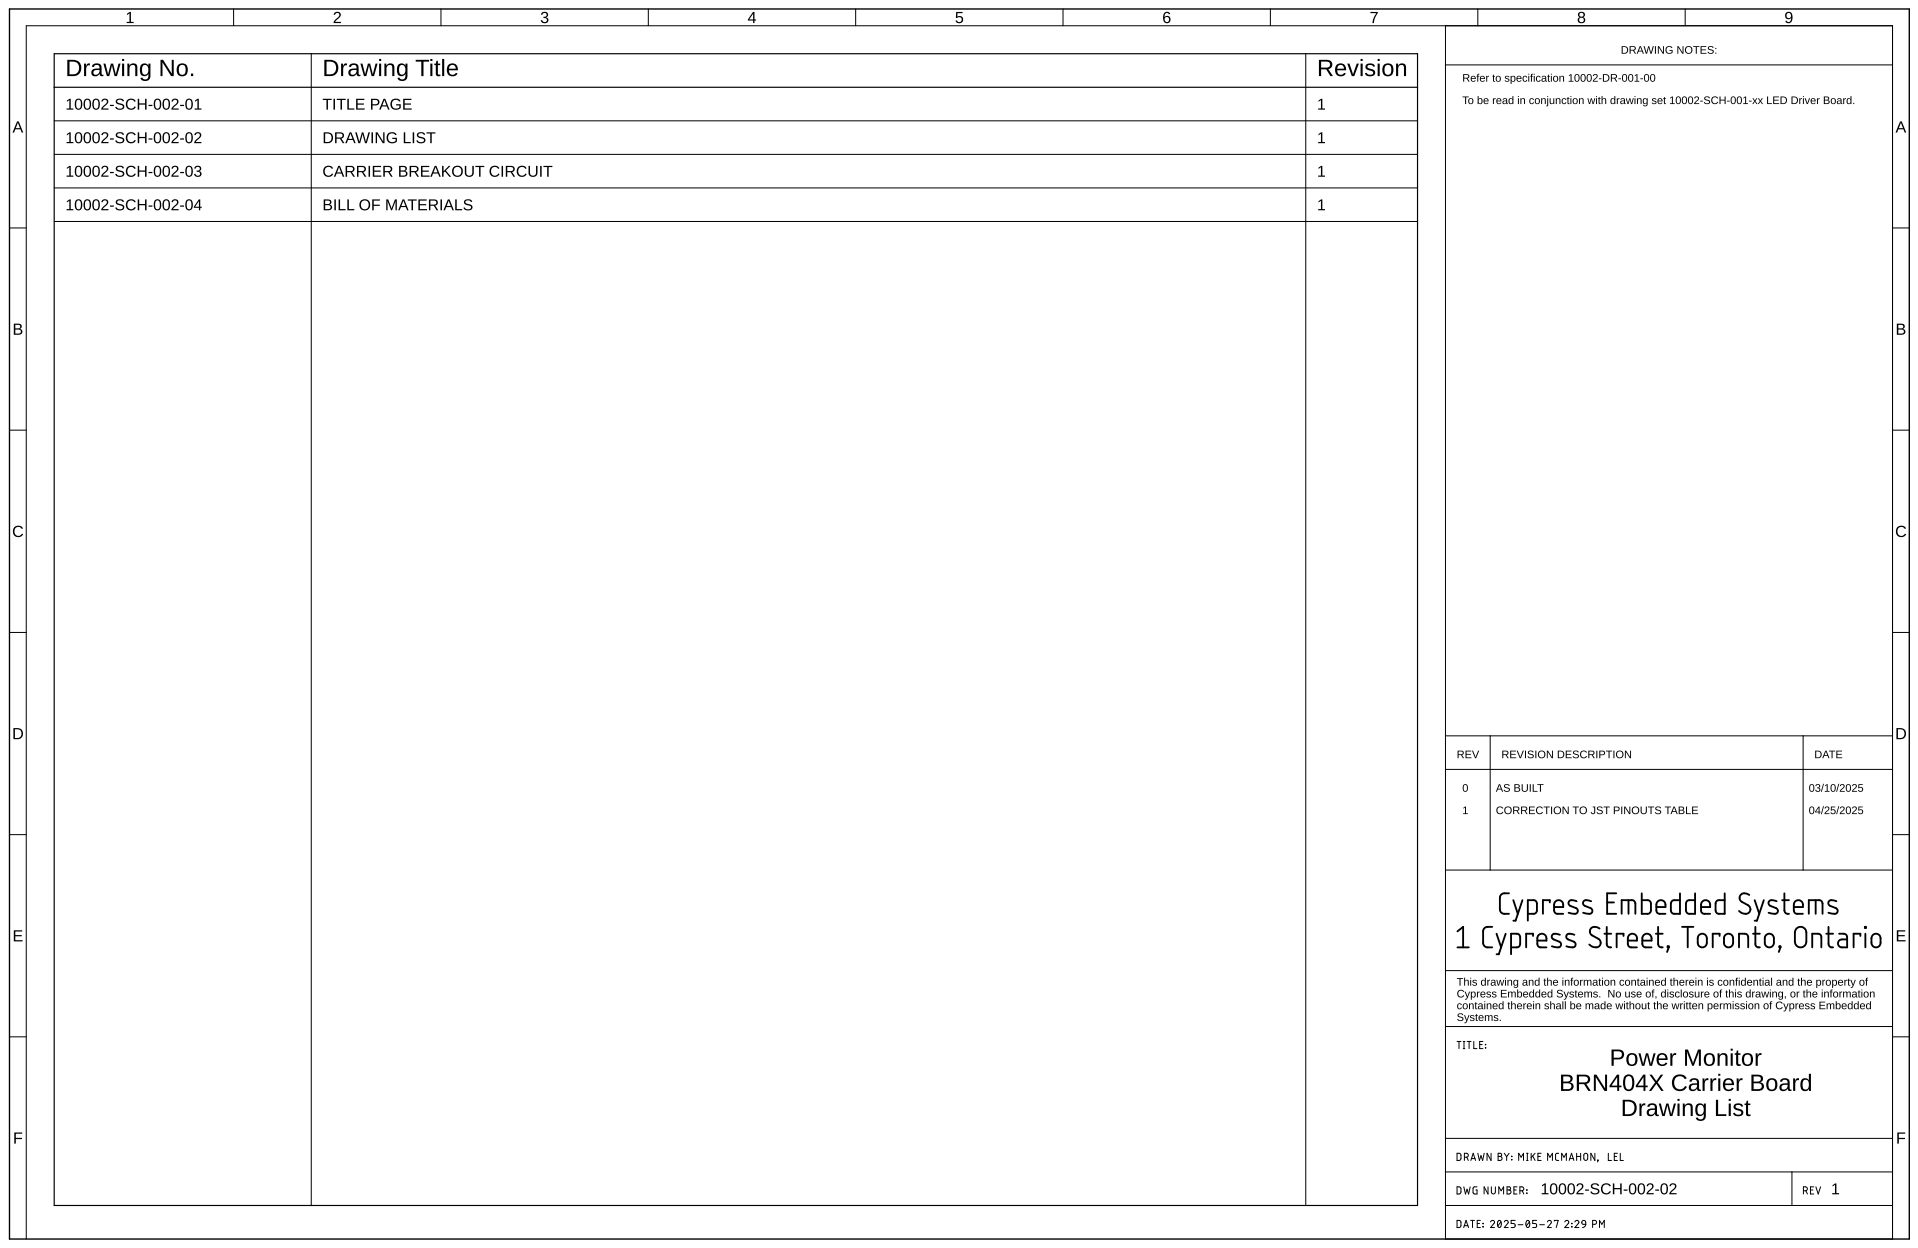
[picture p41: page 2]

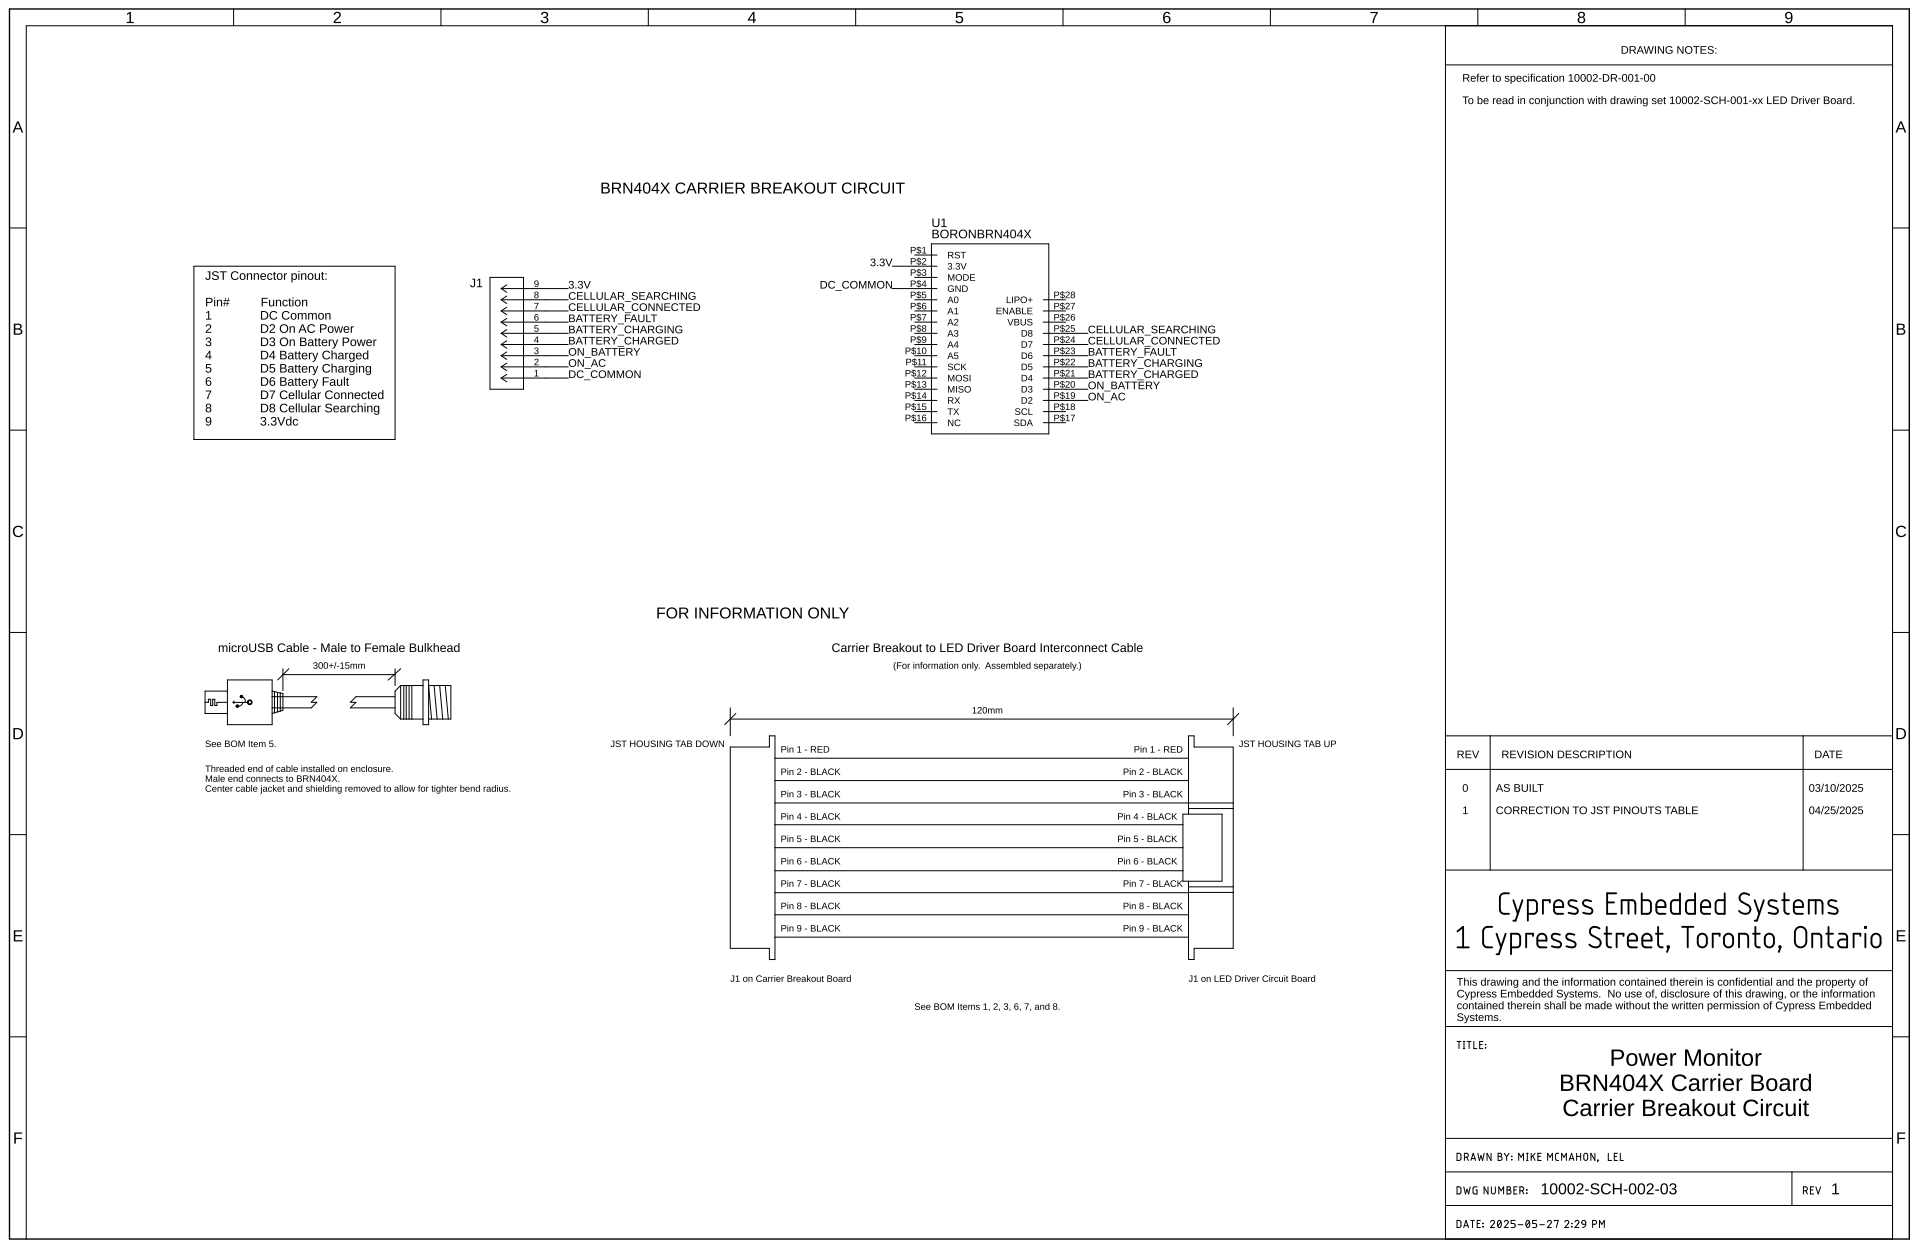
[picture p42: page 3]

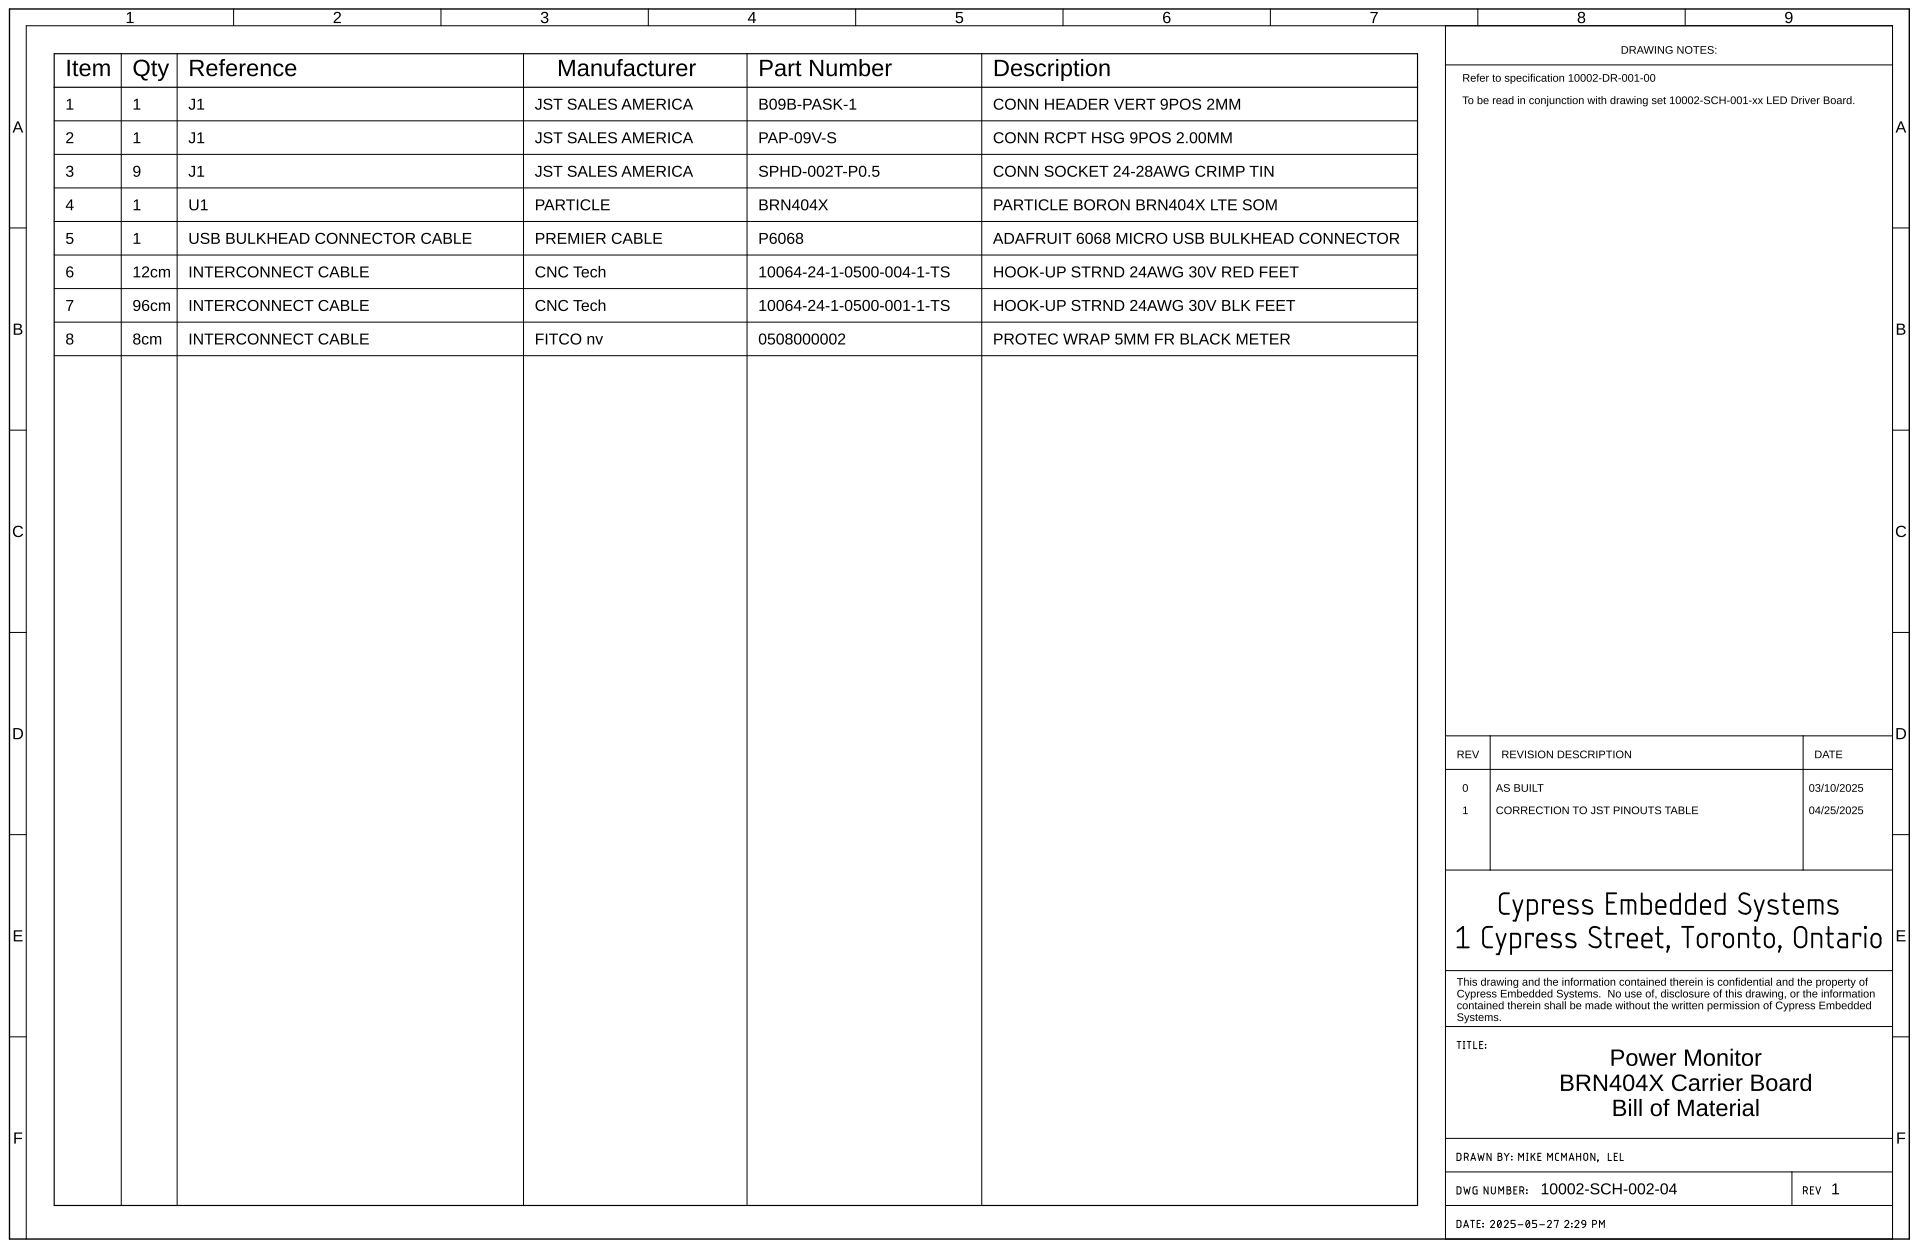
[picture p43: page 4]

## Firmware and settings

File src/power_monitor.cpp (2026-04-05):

/**
  ******************************************************************************
  * Project:    Power Monitor
  * @file    	power_monitor.cpp
  * @author  	Mike McMahon, Cypress Embedded Systems
  * @brief   	This file provides firmware functions that implement the
  *          	power monitoring system.
  *              
  ******************************************************************************
  * @attention
  *
  * <h2><center>&copy; Copyright (c) 2025 Mike McMahon, Cypress Embedded Systems.  All rights reserved.</center></h2>
  *	
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
  ******************************************************************************
  */


/*
 *  I/O MAPPING
 *  NO.     I/O         DESCRIPTION             SYMBOL          LED COLOR 
 *  D2  -   P1.01   -   ON AC POWER         -   onAcPwr     -   (SOLID) GREEN  
 *  D3  -   P1.02   -   ON BATTERY BACKUP   -   onBatPwr    -   (SOLID) RED   
 *  D4  -   P1.08   -   BATTERY CHARGED     -   batCharged  -   (SOLID) GREEN 
 *  D5  -   P1.10   -   BATTERY CHARGING    -   batCharging -   (FLASHING) YELLOW
 *  D6  -   P1.11   -   BATTERY FAULT       -   batFlt      -   (SOLID) RED
 *  D7  -   P1.12   -   LTE CONNECTED       -   onCell      -   (SOLID) GREEN
 *  D8  -   P1.03   -   LTE SEARCHING       -   cellSearch  -   (FLASHING) RED
 *   
 */


// Include Particle Device OS APIs
#include "Particle.h"
#include "power_monitor.h"
#include "battery.h"
#include "cellular.h"
#include "power.h"
#include "datatransmit.h"
#include "shutdown.h"
#include "spark_wiring.h"

// Let Device OS manage the connection to the Particle Cloud
SYSTEM_MODE(AUTOMATIC);

// Run the application and system concurrently in separate threads
SYSTEM_THREAD(ENABLED);

// Object for monitoring power system.
PMIC pmic;

//Declare function prototypes
void init(void);

//Check AC line voltage every 1 second.
Timer powerCheckTimer(1000, checkACLineVoltage, false);

//Check battery status every 1 second.
Timer batteryCheck(1000, batteryStatus, false);

//Check cellular connection every 60 seconds.
Timer cellCheckTimer(60000, testCellularConnection, false);

/*
 *  @brief  Initialization routine called automatically by SoM when system is booted up.
 *  @param  none
 *  @retval none
 */
void setup() {
    
    // The device has booted, reconnect the battery.
	pmic.enableBATFET();

    //initialize variables
	publishFlag = false;
    onAC = false;
    onBattery = false;
    lowBattery = false;
    systemOnBattery = false;
    batteryCharging = false;
    batteryCharged = false;
    batUnknown = false;
    batNotCharging = false;
    batFaulted = false;
    batDisconnected = false;
    defaultDoOnce = false;
    LTEindicatorFlash = false;
    systemConnected = false;
	unknownCount = 0;
    notChargingCount = 0;
    faultCount = 0;
    disconnectCount = 0;

    //initialize digital I/O
	init();

    //Turn on LED indicating that we are waiting for a cellular connection and connection to Particle cloud.
    if (!Cellular.ready() && !Particle.connected()) {
        systemConnected = false;
        digitalWrite(cellSearch, HIGH);
        digitalWrite(onCell, LOW);
    }

    //Wait until connected to cellular network.
    waitUntil(Cellular.ready);

    //Ensure we are connected to the Particle cloud infrastructure.
    waitUntil(Particle.connected);

    //Turn on a LED output indicating cellular and Particle clound are connected.
    if (Cellular.ready() && Particle.connected()) {
        systemConnected = true;
        digitalWrite(cellSearch, LOW);
        digitalWrite(onCell, HIGH);
    }

    // Check whether we are connected to AC line voltage or battery 
    int powerSource = System.powerSource();

    if (powerSource == POWER_SOURCE_BATTERY) {
        //we are on battery
        onBattery = true;
        onAC = false;
        digitalWrite(onBatPwr, HIGH);
        digitalWrite(onAcPwr, LOW);
    }
    else {
        //otherwise we are connected to AC power
        onBattery = false;
        onAC = true;
        digitalWrite(onBatPwr, LOW);
        digitalWrite(onAcPwr, HIGH);
    }
    
    //Send notification to user that the application is booting and connected to cellular.
    //Indicate to user if monitor is on AC power or not.
    if(onBattery) {
         str1 = "Application booting...";
         str2 = "NO AC POWER";
         sendData();
    }
    else {
         str1 = "Application booting...";
         str2 = "AC POWER GOOD";
         sendData();        
    }
    
    //Start timers
	cellCheckTimer.start();
	powerCheckTimer.start();
	batteryCheck.start();
}


/*
 *  @brief  Main routine continuous loop.
 *  @param  none
 *  @retval none
 */
void loop() {
	
    //Must be performed in main thread due to blocking calls of Particle.publish()
	//publish data to Particle cloud and Pushover.  Reset flag after every publish.
	if (publishFlag) {
		sendData();
		publishFlag = false;
	}
	
	//Must be performed in main thread due to blocking calls of delay()
	//Check for low battery conditions and shutdown if necessary.
	//Non-blocking.  Must not be on a timer interrupt callback due to calls to delay().
	lowBatteryLife();
}


/*
 *	@brief	Initialize all physical I/O.
 *	@param	none
 *	@retval	none
 */
 void init(void) {
 
	//Digital outputs - for LED indicators
    onAcPwr = D2;
    onBatPwr = D3;
    batCharged = D4;
    batCharging = D5;
    batFlt = D6;
    onCell = D7;
    cellSearch = D8;

    //Initialize digital outputs
    pinMode(onAcPwr, OUTPUT);
    pinMode(onBatPwr, OUTPUT);
    pinMode(batCharged, OUTPUT);
    pinMode(batCharging, OUTPUT);
    pinMode(batFlt, OUTPUT);
    pinMode(onCell, OUTPUT);
    pinMode(cellSearch, OUTPUT);

    //Set all outputs to known OFF state
    digitalWrite(onAcPwr, LOW);
    digitalWrite(onBatPwr, LOW);
    digitalWrite(batCharged, LOW);
    digitalWrite(batCharging, LOW);
    digitalWrite(batFlt, LOW);
    digitalWrite(onCell, LOW);
    digitalWrite(cellSearch, LOW);
 }

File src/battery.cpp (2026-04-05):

/**
  ******************************************************************************
  * Project:    Power Monitor
  * @file    	battery.cpp
  * @author  	Mike McMahon, Cypress Embedded Systems
  * @brief   	This file implements functions in battery.h
  *          	 
  ******************************************************************************
  * @attention
  *
  * <h2><center>&copy; Copyright (c) 2025 Mike McMahon, Cypress Embedded Systems.  All rights reserved.</center></h2>
  *	
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
  ******************************************************************************
  */

#include "Particle.h"  
#include "battery.h"
#include "datatransmit.h"
#include "power.h"

// Battery status
bool systemOnBattery;
bool batteryCharging;
bool batteryCharged;
bool batUnknown;
bool batNotCharging;
bool batFaulted;
bool batDisconnected;
bool defaultDoOnce;

// Used for battery alarms and faults
int unknownCount;
int notChargingCount;
int faultCount;
int disconnectCount;

// Status LED's
int batCharged;
int batCharging;
int batFlt;

/*
 *  @brief  Check and monitor battery status for faults and current condition.
 *          Low voltage conditions leading to shutdown are covered in shutdown.h .cpp
 *  @param  none
 *  @retval none
 */
void batteryStatus(void)
{
    // Check to see if the battery is connected and charged or charging.
    int batteryState = System.batteryState();

    // If battery is charged
    if (batteryState == BATTERY_STATE_CHARGED && !batteryCharged)
    {
        batteryCharged = true;
        batteryCharging = false;
        systemOnBattery = false;
        digitalWrite(batFlt, LOW);
        digitalWrite(batCharging, LOW);
        digitalWrite(batCharged, HIGH);
    }

    // If battery is charging
    if (batteryState == BATTERY_STATE_CHARGING && !batteryCharging)
    {
        batteryCharged = false;
        systemOnBattery = false;
        batteryCharging = true;
        digitalWrite(batFlt, LOW);
        digitalWrite(batCharged, LOW);
        digitalWrite(batCharging, LOW);
    }
    else if (batteryState == BATTERY_STATE_CHARGING && batteryCharging)
    {
        batteryCharging = false;
        digitalWrite(batFlt, LOW);
        digitalWrite(batCharged, LOW);
        digitalWrite(batCharging, HIGH);
    }

    // If we are on battery power turn off the battery charged and charging status LED's
    if (onBattery && !systemOnBattery)
    {
        systemOnBattery = true;
        batteryCharged = false;
        batteryCharging = false;
        digitalWrite(batCharged, LOW);
        digitalWrite(batCharging, LOW);
    }

    // Battery fault handling
    // Add delay counter to each fault state to ignore transient events.  Only faults lasting longer than 10 seconds should be noted.
    switch (batteryState)
    {
    case BATTERY_STATE_UNKNOWN:
        unknownCount++;
        if ((unknownCount > 10) && !batUnknown)
        {
            // to prevent overflow errors
            unknownCount = 0;
            batUnknown = true;
            defaultDoOnce = false;
            batteryCharged = false;
            batteryCharging = false;
            digitalWrite(batCharged, LOW);
            digitalWrite(batCharging, LOW);
            digitalWrite(batFlt, HIGH);
            str1 = "Battery";
            str2 = "State Unknown";
            publishFlag = true;
        }
        break;

    case BATTERY_STATE_NOT_CHARGING:
        notChargingCount++;
        if ((notChargingCount > 10) && !batNotCharging)
        {
            // to prevent overflow errors
            notChargingCount = 0;
            batNotCharging = true;
            defaultDoOnce = false;
            batteryCharged = false;
            batteryCharging = false;
            digitalWrite(batCharged, LOW);
            digitalWrite(batCharging, LOW);
            digitalWrite(batFlt, HIGH);
            str1 = "Battery";
            str2 = "Not Charging";
            publishFlag = true;
        }
        break;

    case BATTERY_STATE_FAULT:
        faultCount++;
        if ((faultCount > 10) && !batFaulted)
        {
            // to prevent overflow errors
            faultCount = 0;
            batFaulted = true;
            defaultDoOnce = false;
            batteryCharged = false;
            batteryCharging = false;
            digitalWrite(batCharged, LOW);
            digitalWrite(batCharging, LOW);
            digitalWrite(batFlt, HIGH);
            str1 = "Battery";
            str2 = "Fault";
            publishFlag = true;
        }
        break;

    case BATTERY_STATE_DISCONNECTED:
        disconnectCount++;
        if ((disconnectCount > 10) && !batDisconnected)
        {
            // to prevent overflow errors
            disconnectCount = 0;
            batDisconnected = true;
            defaultDoOnce = false;
            batteryCharged = false;
            batteryCharging = false;
            digitalWrite(batCharged, LOW);
            digitalWrite(batCharging, LOW);
            digitalWrite(batFlt, HIGH);
            str1 = "Battery";
            str2 = "Disconnected";
            publishFlag = true;
        }
        break;

    default:
        // Do only once to prevent multiple writes
        if (!defaultDoOnce)
        {
            defaultDoOnce = true;
            batUnknown = false;
            unknownCount = 0;
            batNotCharging = false;
            notChargingCount = 0;
            batFaulted = false;
            faultCount = 0;
            batDisconnected = false;
            disconnectCount = 0;
            digitalWrite(batFlt, LOW);
        }
        break;
    }
}
